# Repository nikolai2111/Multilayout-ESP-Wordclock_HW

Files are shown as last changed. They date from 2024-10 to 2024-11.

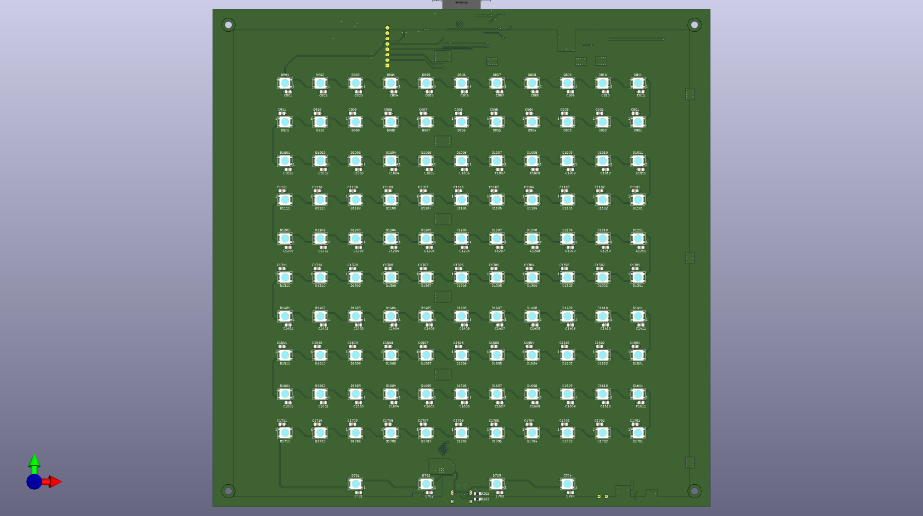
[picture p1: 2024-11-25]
PCB-3D_Top_A.png

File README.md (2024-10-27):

# Multilayout-ESP-Wordclock_HW
This is the first unofficial hardware (PCB) for the [Multilayout-ESP-Wordclock](https://github.com/ESPWortuhr/Multilayout-ESP-Wordclock). The currently supported layout is a 10x11 with the 4 LEDs in the corner (total 114 LEDs). The dimensions are 240 x 240 mm. In the future, maybe more than one PCBs will be available as branch, but we will see how it goes.

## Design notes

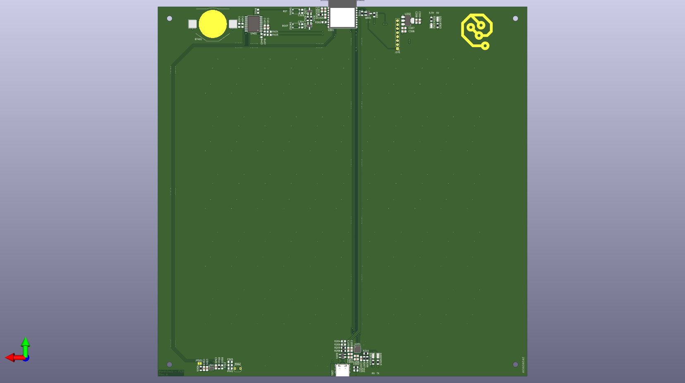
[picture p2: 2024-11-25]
PCB-3D_Bot_A.png

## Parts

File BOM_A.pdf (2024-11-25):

Reference | Value | Footprint | Qty | DNP | Manufacturer | Manufacturer Part no. | Vendor 1 | Vendor 1 Part no. | Vendor 2 | Vendor 2 Part no. | Comment
BT401 | CR2032 | Battery:BatteryHolder_Keystone_3002_1x2032 | 1 | | Keystone Electronics | 2898 | Digikey | 36-2898-ND | LCSC | C6379018
C201, C303, C304, C404, C502 | 0.1µF | Capacitor_SMD:C_0805_2012Metric_Pad1.18x1.45mm_HandSolder | 5 | DNP | Samsung Electro-Mechanics | CL21B104KCFNNNE | Digikey | 1276-6840-1-ND | LCSC | C28233 | Best fit from the JLCPCB "Basic" components
C202, C204, C205, C301, C306, C309, C401, C503 | 10µF | Capacitor_SMD:C_0805_2012Metric_Pad1.18x1.45mm_HandSolder | 8 | | Samsung Electro-Mechanics | CL21A106KOQNNNE | Digikey | 1276-1096-1-ND | LCSC | C1713 | Best fit from the JLCPCB "Basic" components
C203, C305, C505 | 1µF | Capacitor_SMD:C_0805_2012Metric_Pad1.18x1.45mm_HandSolder | 3 | | Samsung Electro-Mechanics | CL21B105KPFNNNE | Digikey | 1276-1275-2-ND | LCSC | C107367 | Best fit from the JLCPCB "Basic" components

C206, C207, C208, C302, C307, C308, C402, C504,
C701, C702, C703, C704, C801, C802, C803, C804, C805, C806, C807, C808, C809, C810, C811, C901, C902, C903, C904, C905, C906, C907, C908, C909, C910, C911, C1001, C1002, C1003, C1004, C1005, C1006, C1007, C1008, C1009, C1010, C1011, C1101, C1102, C1103, C1104, C1105, C1106, C1107, C1108, C1109, C1110, C1111, C1201, C1202, C1203, C1204, C1205, C1206, C1207, C1208, C1209, C1210, C1211, C1301, C1302, C1303, C1304, C1305, C1306, C1307, C1308, C1309, C1310, C1311, C1401, C1402, C1403, C1404, C1405, C1406, C1407, C1408, C1409, C1410, C1411, C1501, C1502, C1503, C1504, C1505, C1506, C1507, C1508, C1509, C1510, C1511, C1601, C1602, C1603, C1604, C1605, C1606, C1607, C1608, C1609, C1610, C1611, C1701, C1702, C1703, C1704, C1705, C1706, C1707, C1708, C1709, C1710, C1711
0.1µF | Capacitor_SMD:C_0805_2012Metric_Pad1.18x1.45mm_HandSolder | 122 | Samsung Electro-Mechanics | CL21B104KCFNNNE | Digikey | 1276-6840-1-ND | LCSC | C28233 | Best fit from the JLCPCB "Basic" components
C403 | 1µF | Capacitor_SMD:C_0805_2012Metric_Pad1.18x1.45mm_HandSolder | 1 | DNP | Samsung Electro-Mechanics | CL21B105KPFNNNE | Digikey | 1276-1275-2-ND | LCSC | C107367 | Best fit from the JLCPCB "Basic" components
C501 | 10µF | Capacitor_SMD:C_0805_2012Metric_Pad1.18x1.45mm_HandSolder | 1 | DNP | Samsung Electro-Mechanics | CL21A106KOQNNNE | Digikey | 1276-1096-1-ND | LCSC | C1713 | Best fit from the JLCPCB "Basic" components
D201 | SP0503BAHTG | Package_TO_SOT_SMD:SOT-143_Handsoldering | 1 | | Littelfuse Inc. | SP0503BAHTG | Digikey | F2715CT-ND | LCSC | C7074
D202, D203 | green | LED_SMD:LED_0805_2012Metric_Pad1.15x1.40mm_HandSolder | 2 | | Lite-On Inc. | LTST-C171GKT | Digikey | 160-1423-1-ND | LCSC | C913075
D301 | red | LED_SMD:LED_0805_2012Metric_Pad1.15x1.40mm_HandSolder | 1 | | Lite-On Inc. | LTST-C171KRKT | Digikey | 160-1427-1-ND | LCSC | C284871
D302 | orange | LED_SMD:LED_0805_2012Metric_Pad1.15x1.40mm_HandSolder | 1 | | Lite-On Inc. | LTST-C170KFKT | Digikey | 160-1413-1-ND | LCSC | C284931
D701, D702, D703, D704, D801, D802, D803, D804, D805, D806, D807, D808, D809, D810, D811, D901, D902, D903, D904, D905, D906, D907, D908, D909, D910, D911, D1001, D1002, D1003, D1004, D1005, D1006, D1007, D1008, D1009, D1010, D1011, D1101, D1102, D1103, D1104, D1105, D1106, D1107, D1108, D1109, D1110, D1111, D1201, D1202, D1203, D1204, D1205, D1206, D1207, D1208, D1209, D1210, D1211, D1301, D1302, D1303, D1304, D1305, D1306, D1307, D1308, D1309, D1310, D1311, D1401, D1402, D1403, D1404, D1405, D1406, D1407, D1408, D1409, D1410, D1411, D1501, D1502, D1503, D1504, D1505, D1506, D1507, D1508, D1509, D1510, D1511, D1601, D1602, D1603, D1604, D1605, D1606, D1607, D1608, D1609, D1610, D1611, D1701, D1702, D1703, D1704, D1705, D1706, D1707, D1708, D1709, D1710, D1711
WS2812B | LED_SMD:LED_WS2812B_PLCC4_5.0x5.0mm_P3.2mm | 114 | - | WS2812B | Digikey | 1568-COM-16347CT-ND | LCSC | C22461793
J101 | Conn_01x08_Pin | Connector_PinHeader_2.54mm:PinHeader_1x08_P2.54mm_Vertical | 1 | DNP | - | - | - | - | - | -
J201 | USB_C_Receptacle_US B2.0_16P | Connector_USB:USB_C_Receptacle_GCT_USB4105-xx-A_16P_TopMnt_Horizontal | 1 | | GCT | USB4105-GF-A | Digikey | 2073-USB4105-GF-ACT-ND | LCSC | C3020560
Q201, Q202 | NPN BJT | Package_TO_SOT_SMD:SOT-23_Handsoldering | 2 | | - | - | Digikey | 353-MMS8050-H-TPCT-ND | LCSC | C49581 | General purpose NPN transistor
Q601 | BSS138 | Package_TO_SOT_SMD:SOT-23_Handsoldering | 1 | | - | BSS138 | Digikey | BSS138CT-ND | LCSC | C518792 | General purpose N-channel MOSFET
R201, R208, R209 | 0R | Resistor_SMD:R_0805_2012Metric_Pad1.20x1.40mm_HandSolder | 3 | | YAGEO | RC0805JR-070RL | Digikey | 311-0.0ARCT-ND | LCSC | C96345 | Best fit from the JLCPCB "Basic" components
R202, R203, R303 | 5.1k | Resistor_SMD:R_0805_2012Metric_Pad1.20x1.40mm_HandSolder | 3 | | YAGEO | RC0805FR-075K1L | Digikey | 311-5.10KCRCT-ND | LCSC | C84375 | Best fit from the JLCPCB "Basic" components
R204, R205, R401, R404, R405, R503 | 0R | Resistor_SMD:R_0805_2012Metric_Pad1.20x1.40mm_HandSolder | 6 | DNP | YAGEO | RC0805JR-070RL | Digikey | 311-0.0ARCT-ND | LCSC | C96345 | Best fit from the JLCPCB "Basic" components
R206 | 22.1k | Resistor_SMD:R_0805_2012Metric_Pad1.20x1.40mm_HandSolder | 1 | | YAGEO | RC0805FR-0722K1L | Digikey | 311-22.1KCRCT-ND | LCSC | C273840
R207 | 47.5k | Resistor_SMD:R_0805_2012Metric_Pad1.20x1.40mm_HandSolder | 1 | | YAGEO | RC0805FR-0747K5L | Digikey | 311-47.5KCRCT-ND | LCSC | C137519
R210, R213, R214, R304, R504 | 1k | Resistor_SMD:R_0805_2012Metric_Pad1.20x1.40mm_HandSolder | 5 | | YAGEO | RC0805FR-071KL | Digikey | 311-1.00KCRCT-ND | LCSC | C95781 | Best fit from the JLCPCB "Basic" components
R211, R212, R301, R505, R601, R602 | 10k | Resistor_SMD:R_0805_2012Metric_Pad1.20x1.40mm_HandSolder | 6 | | YAGEO | RC0805FR-0710KL | Digikey | 311-10.0KCRCT-ND | LCSC | C84376 | Best fit from the JLCPCB "Basic" components
R302, R402, R403, R501 | 10k | Resistor_SMD:R_0805_2012Metric_Pad1.20x1.40mm_HandSolder | 4 | DNP | YAGEO | RC0805FR-0710KL | Digikey | 311-10.0KCRCT-ND | LCSC | C84376 | Best fit from the JLCPCB "Basic" components
R502 | LDR07 | OptoDevice:R_LDR_5.1x4.3mm_P3.4mm_Vertical | 1 | DNP | - | - | - | - | - | -
SW301, SW302 | SW_Push | Button_Switch_SMD:SW_SPST_PTS810 | 2 | | C&K; | PTS810 SJK 250 SMTR LFS | Digikey | CKN10503CT-ND | LCSC | C221896
U201 | CP2102N-Axx-xQFN24 | Package_DFN_QFN:QFN-24-1EP_4x4mm_P0.5mm_EP2.6x2.6mm_ThermalVias | 1 | | Silicon Labs | CP2102N-A02-GQFN24R | Digikey | 336-5888-2-ND | LCSC | C969151
U301 | ESP32-C3-WROOM-02 | RF_Module:ESP32-C3-WROOM-02 | 1 | | Espressif Systems | ESP32-C3-WROOM-02-N4 | Digikey | 1965-ESP32-C3-WROOM-02 -N4TR-ND | LCSC | C2934560
U302 | TLV1117LV33 | Package_TO_SOT_SMD:SOT-223-3_TabPin2 | 1 | | Texas Instruments | TLV1117LV33DCYR | Digikey | 296-28778-2-ND | LCSC | C15578
U401 | DS3231M | Package_SO:SOIC-16W_7.5x10.3mm_P1.27mm | 1 | | Analog Devices Inc./Maxim Integrated | DS3231M+TRL | Digikey | DS3231M+TRLCT-ND | LCSC | C9866 | LCSC, only has the compatible DS3231SN in stock
U501 | BH1750xxx-xx | Package_TO_SOT_SMD:HVSOF6 | 1 | | Rohm Semiconductor | BH1750FVI-TR | Digikey | BH1750FVICT-ND | LCSC | C78960

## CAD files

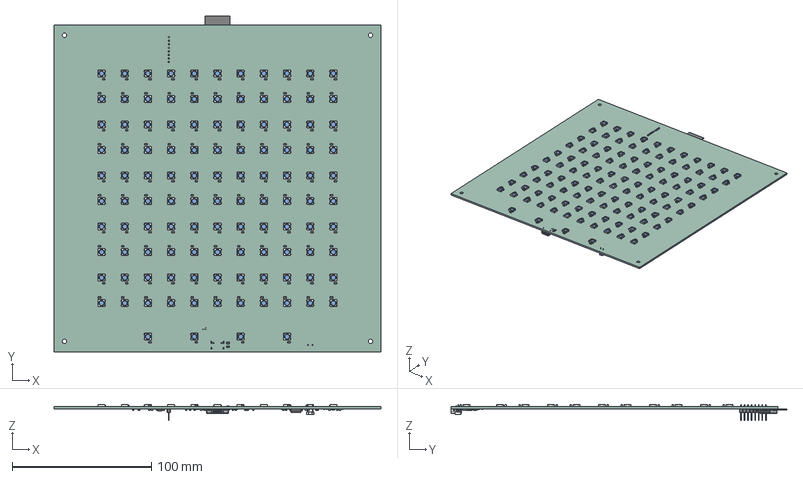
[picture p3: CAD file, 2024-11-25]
ESP-Wordclock_A.step
235.0 x 241.2 x 11.8 mm
C_0805_2012Metric x 140
LED_WS2812B_PLCC4_50x50mm_P32mm x 114
R_0805_2012Metric x 29
SOT_23 x 3
SOT_223
USB_C_Receptacle_16P_TopMnt_Horizontal_GCT_USB4105-xx-A
R_LDR_5.1x4.3mm_P3.4mm_Vertical
LED_0805_2012Metric x 4
SOIC_16W_75x103mm_P127mm
ESP32-C3-WROOM-02
QFN-24-1EP_4x4mm_Pitch0.5mm
PinHeader_1x08_P254mm_Vertical
SOT_143
HVSOF6
ESP-Wordclock_PCB

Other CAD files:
ESP-Wordclock.step

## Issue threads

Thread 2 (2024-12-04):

Remove UART LEDs

nikolai2111, 2024-12-04:
Remove the ledss D202 & D203 and its resistors R213 & R214, because the gpios are not configured by default, so the leds are not working.

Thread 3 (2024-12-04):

No external pull-up resistors

nikolai2111, 2024-12-04:
I2C needs pull-up resistors. The board does not have external pull-up resistors so the internal of the ESP32-C3 has to be used in code!

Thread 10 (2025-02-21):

USB-C PD driver

dbambus, 2025-02-21:
Hey,

Would a USB-C PD be possible? With a 12V input, there might be better power handling capabilities.

Mit freundlichen Grüßen
David

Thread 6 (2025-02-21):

Mounting holes

dbambus, 2025-02-21:
Hey,

an addition would be to place mounting holes for wall mounting the clock.

Suggestion would be:

- Top Mid
- 5cm Left and 5cm right from the mid

Mit freundlichen Grüßen
David

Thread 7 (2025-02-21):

Solder bridges for Vcc LEDs

dbambus, 2025-02-21:
Hey,

some prefer not to have status LEDs for VCC on the PCB. Maybe some solder Bridges to cu would be good.

Mit freundlichen Grüßen
David

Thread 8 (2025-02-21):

Pinout after the last LED

dbambus, 2025-02-21:
Hey,

there are frame designs which use additional stripes around the outer perimeter of the clock to enable some sort of Ambient light. A pinout to glue normal stripes to the back of the clock with traces in the corners.

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

Mit freundlichen Grüßen
David

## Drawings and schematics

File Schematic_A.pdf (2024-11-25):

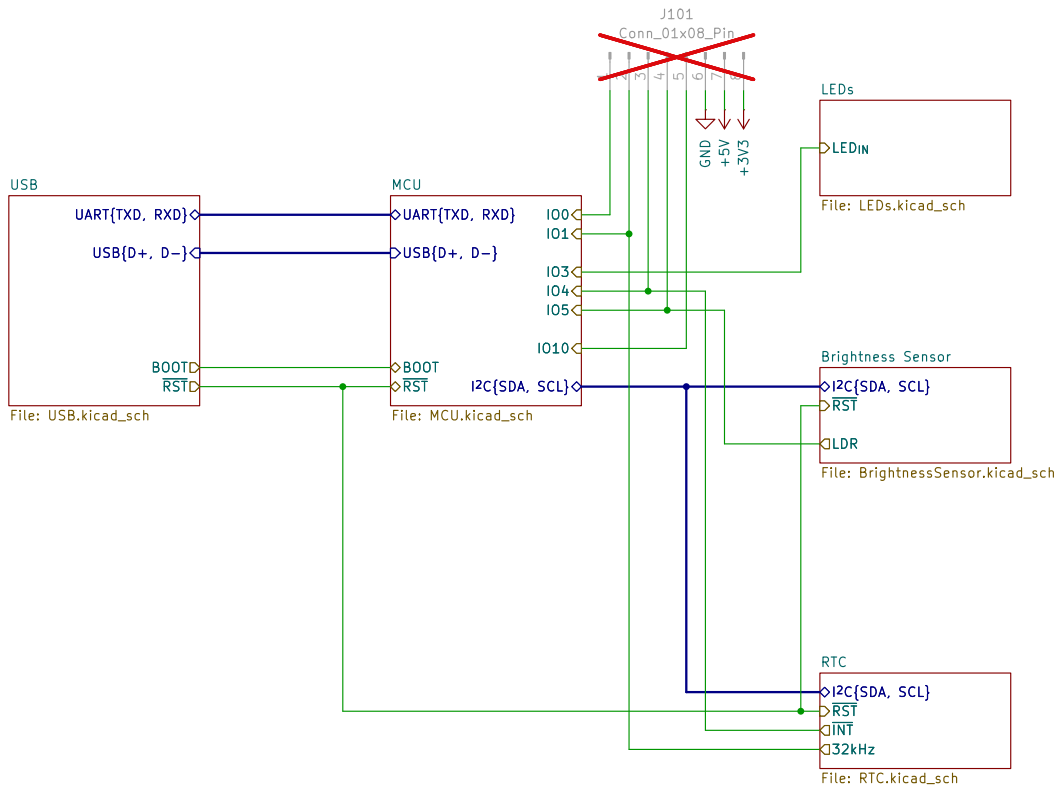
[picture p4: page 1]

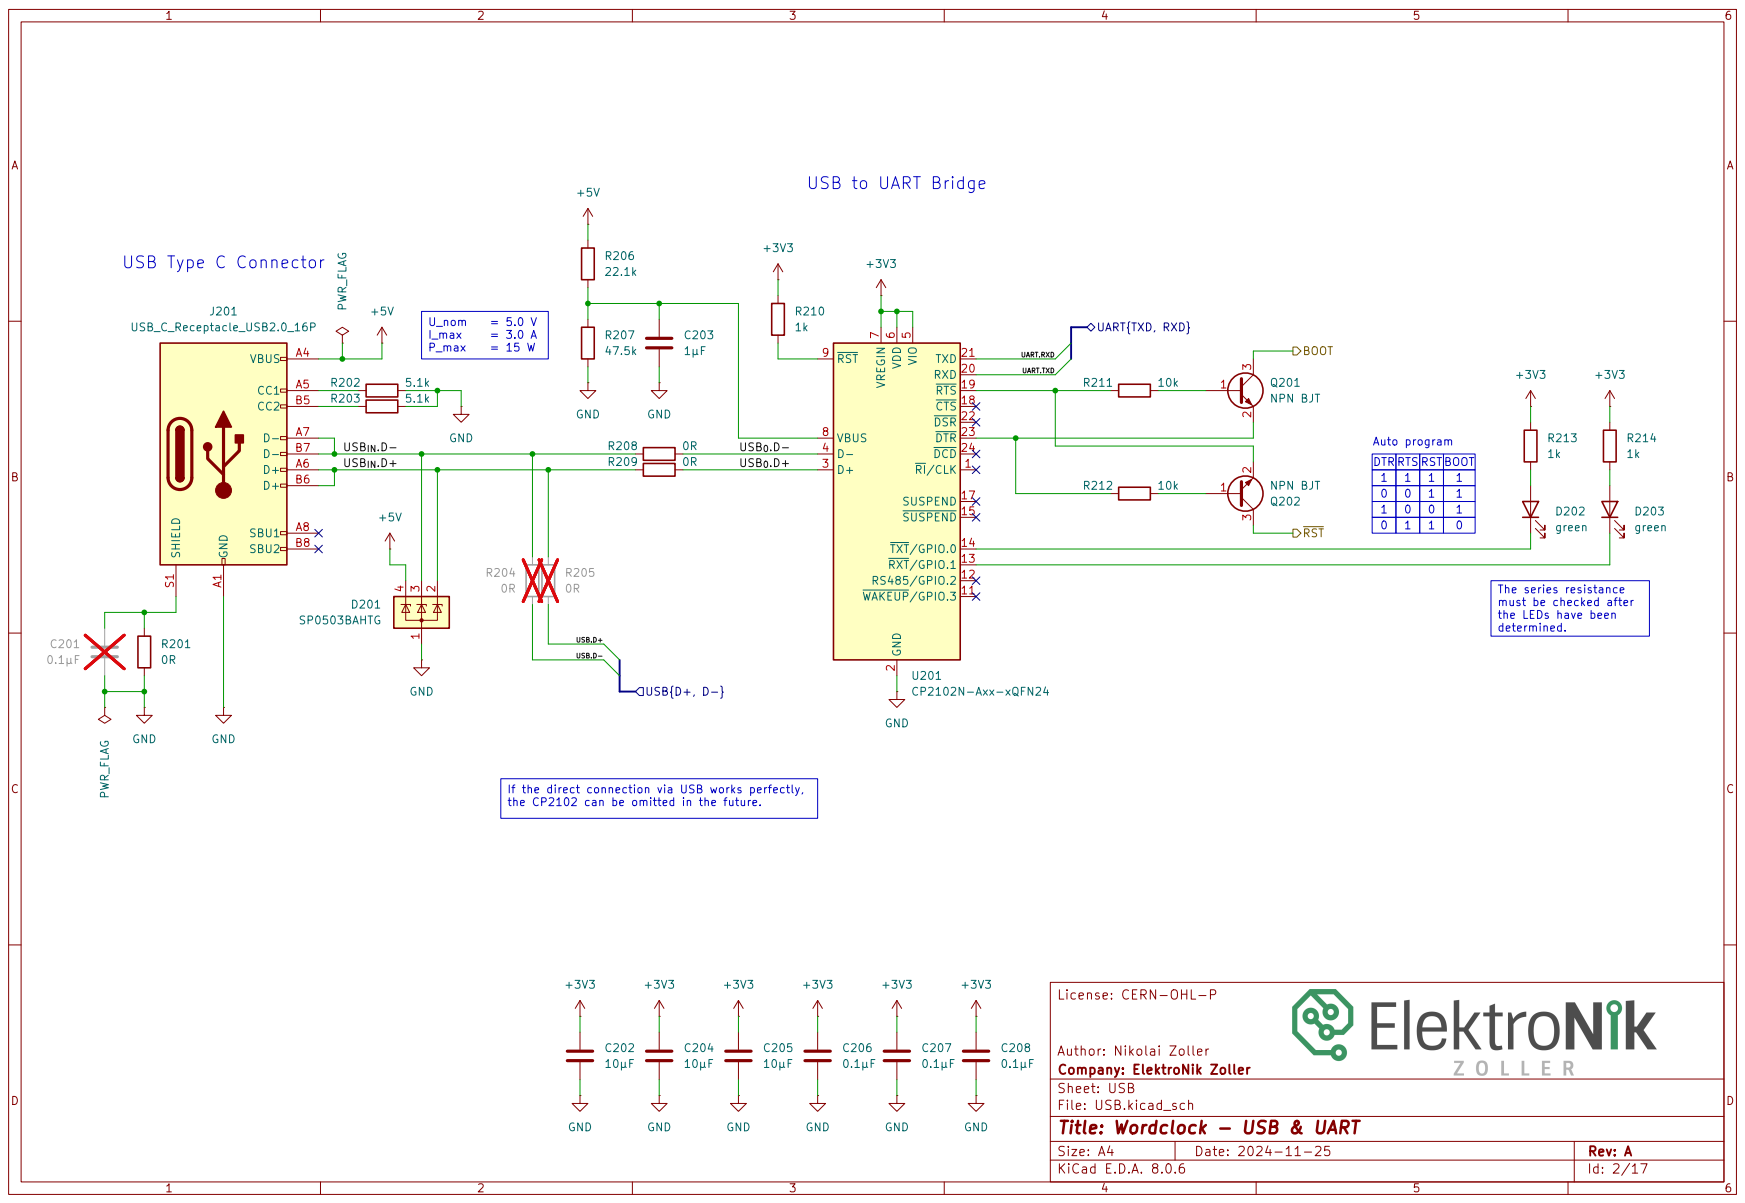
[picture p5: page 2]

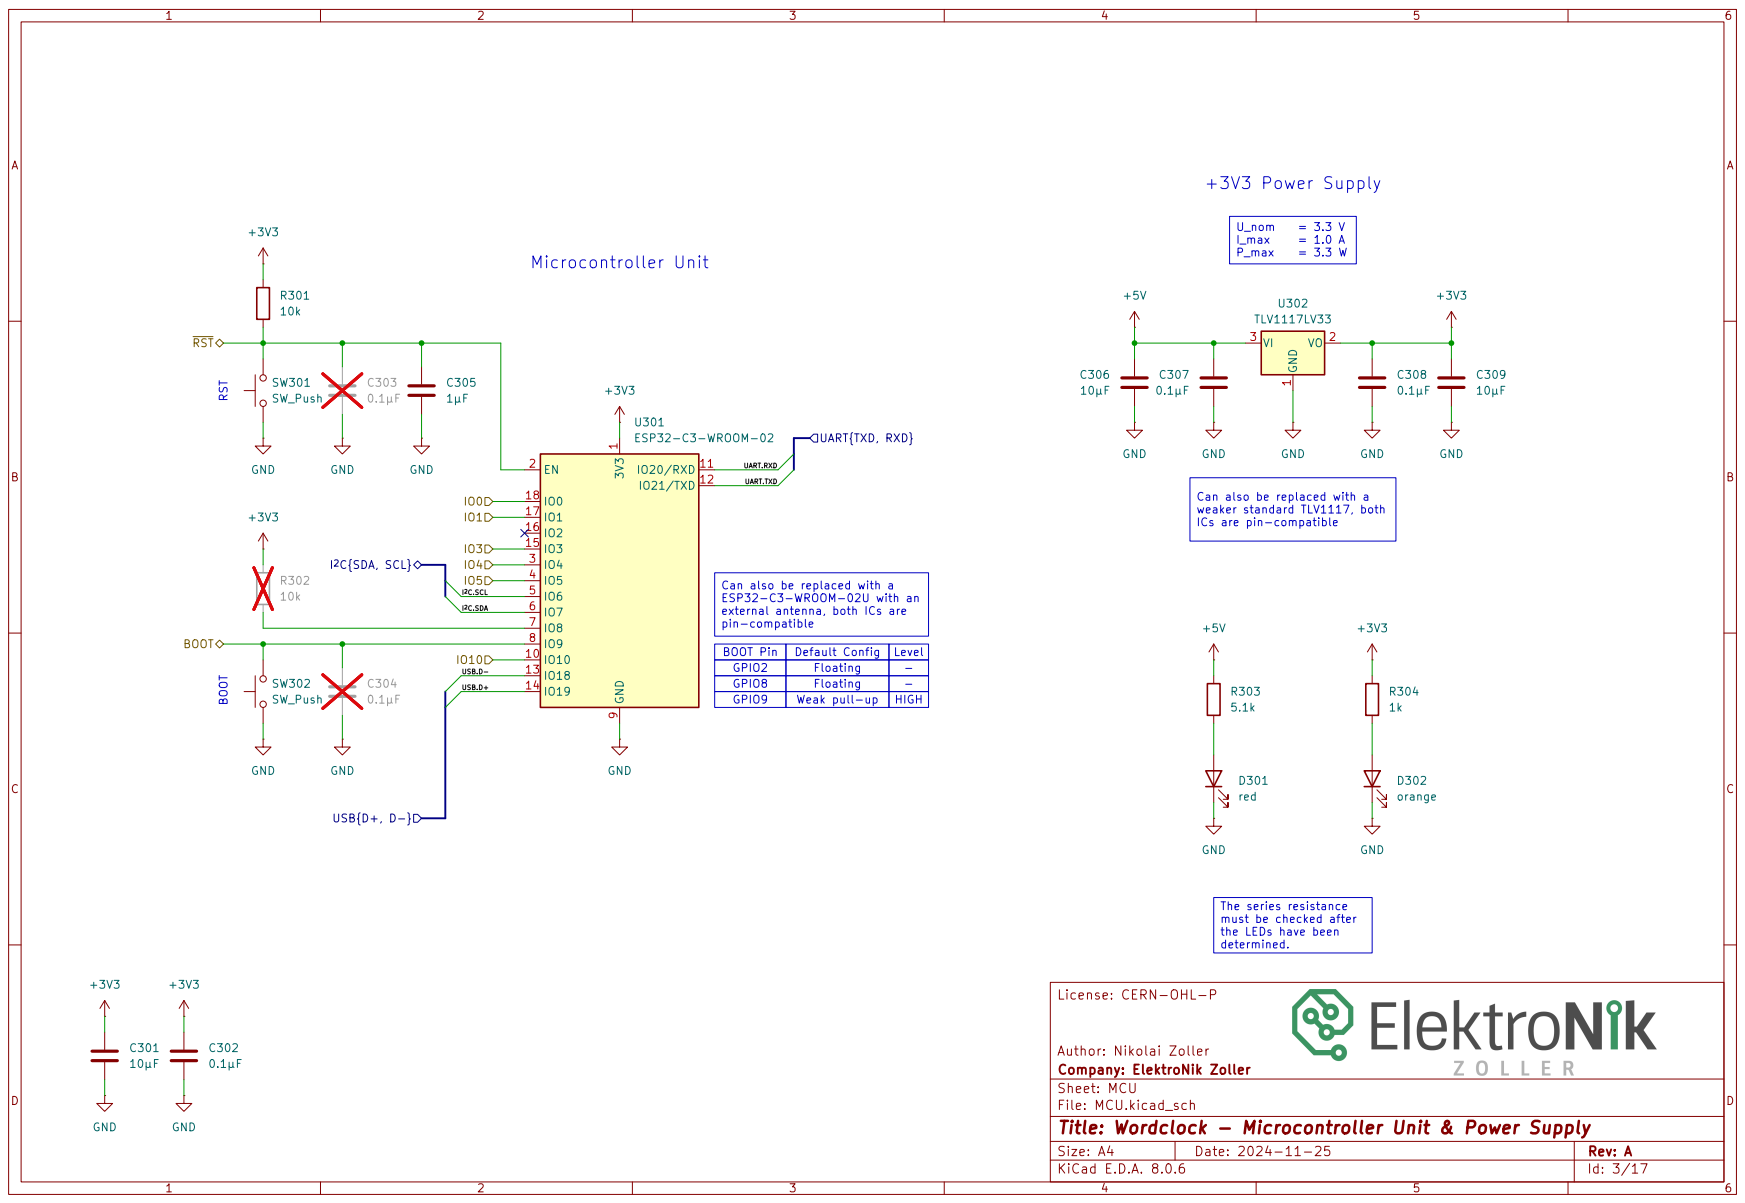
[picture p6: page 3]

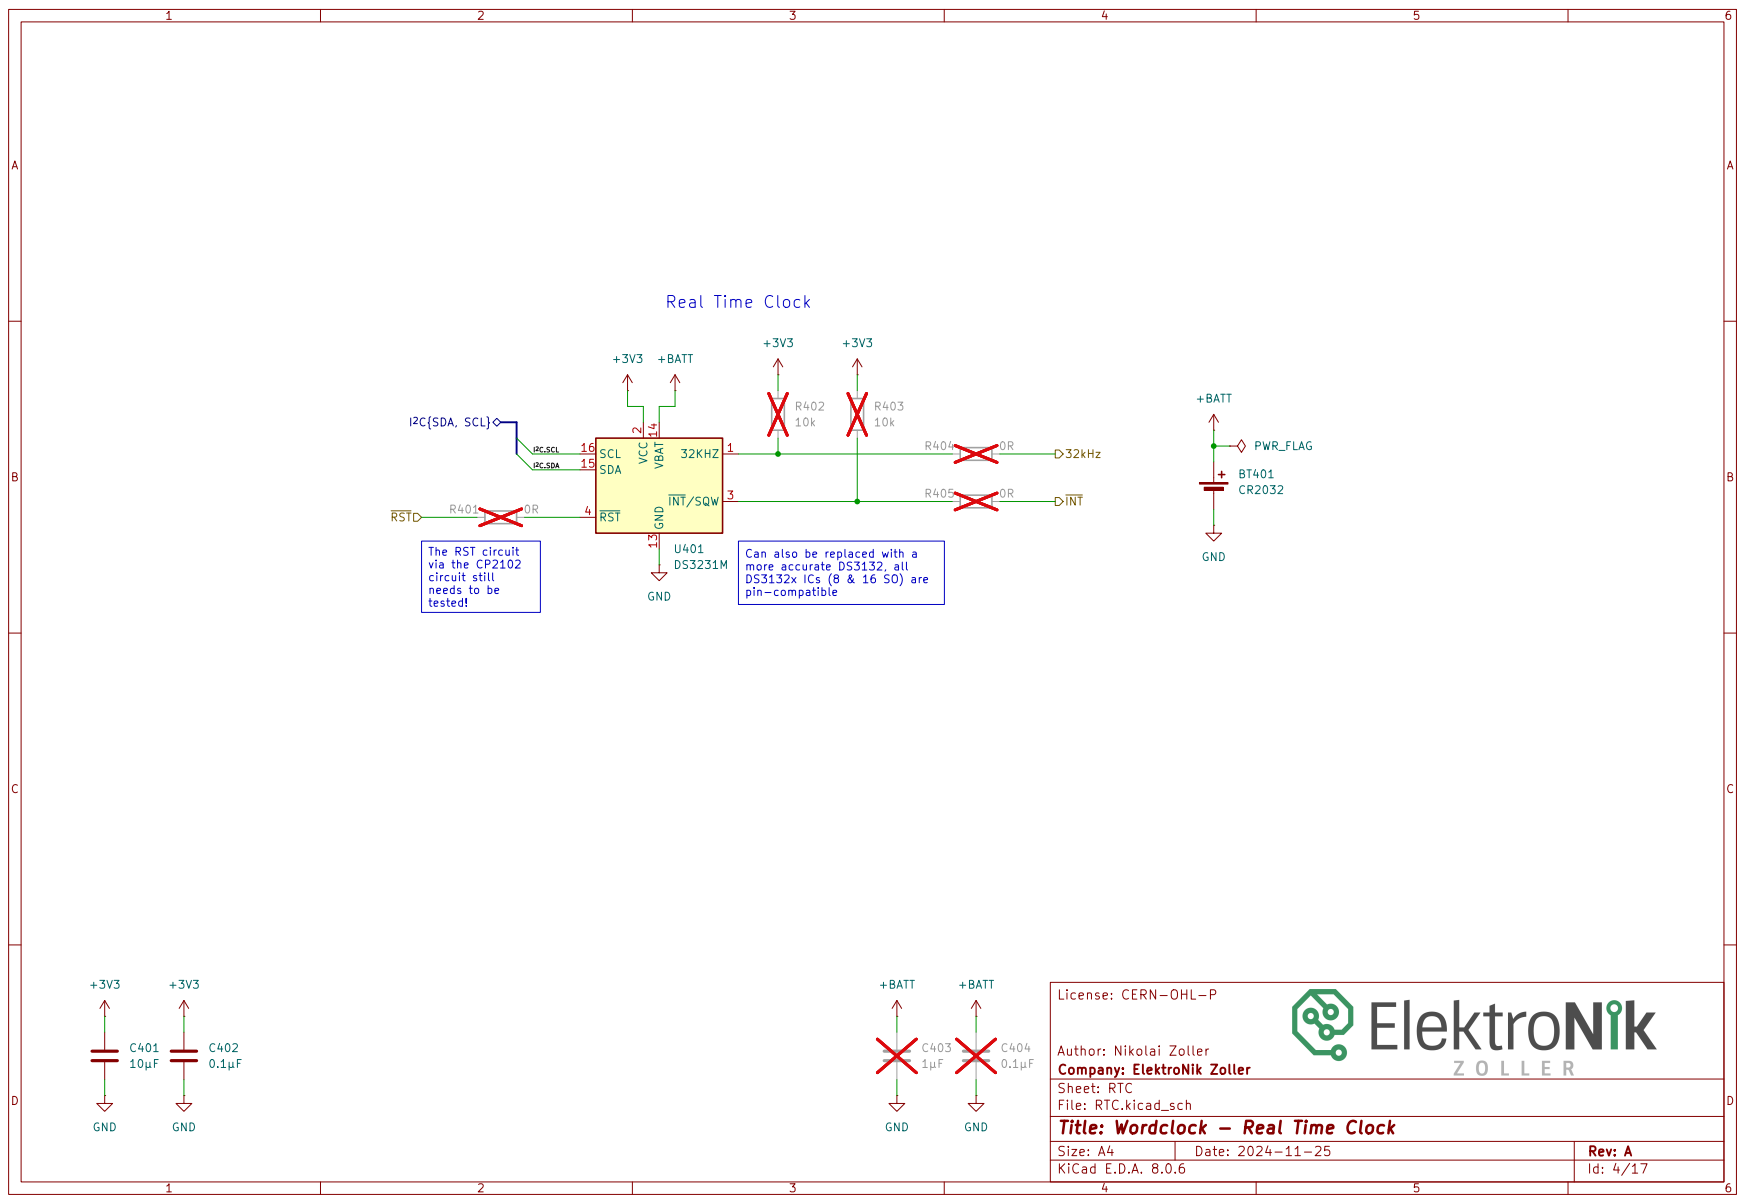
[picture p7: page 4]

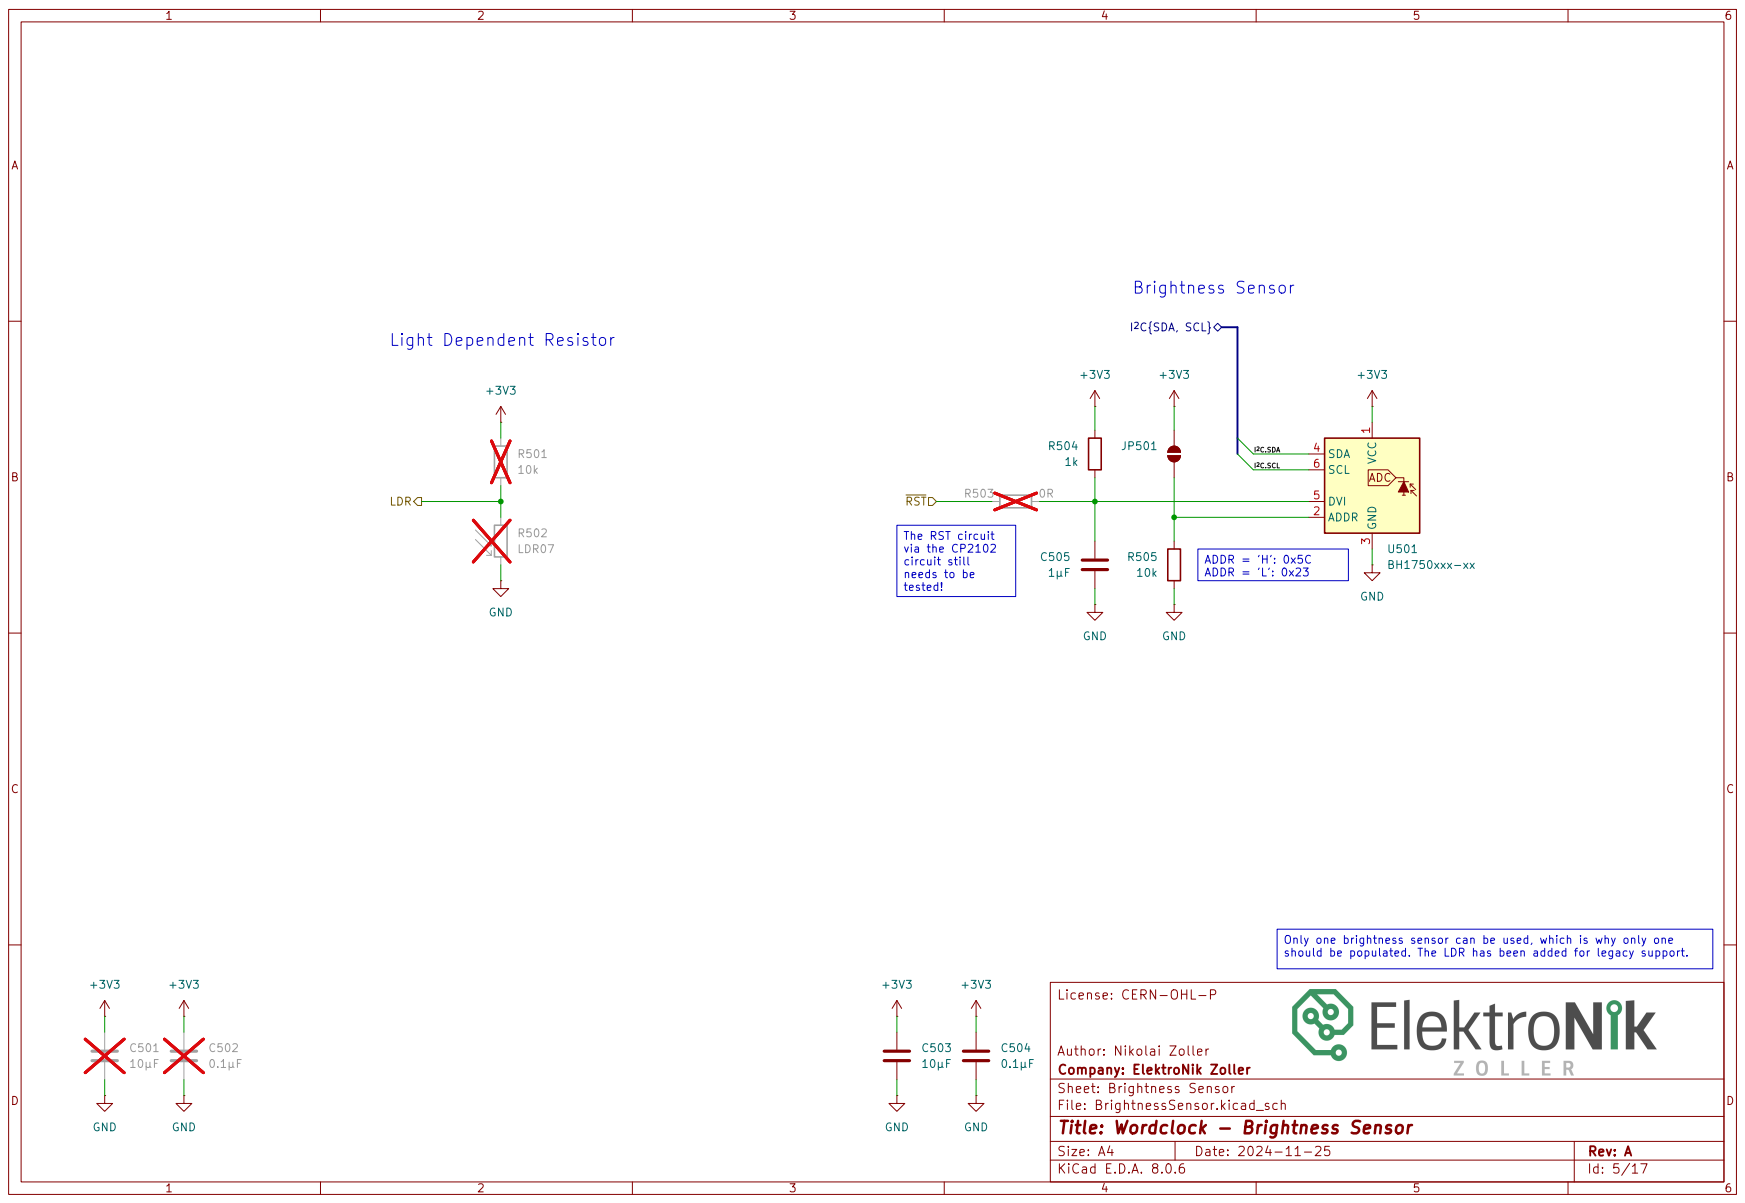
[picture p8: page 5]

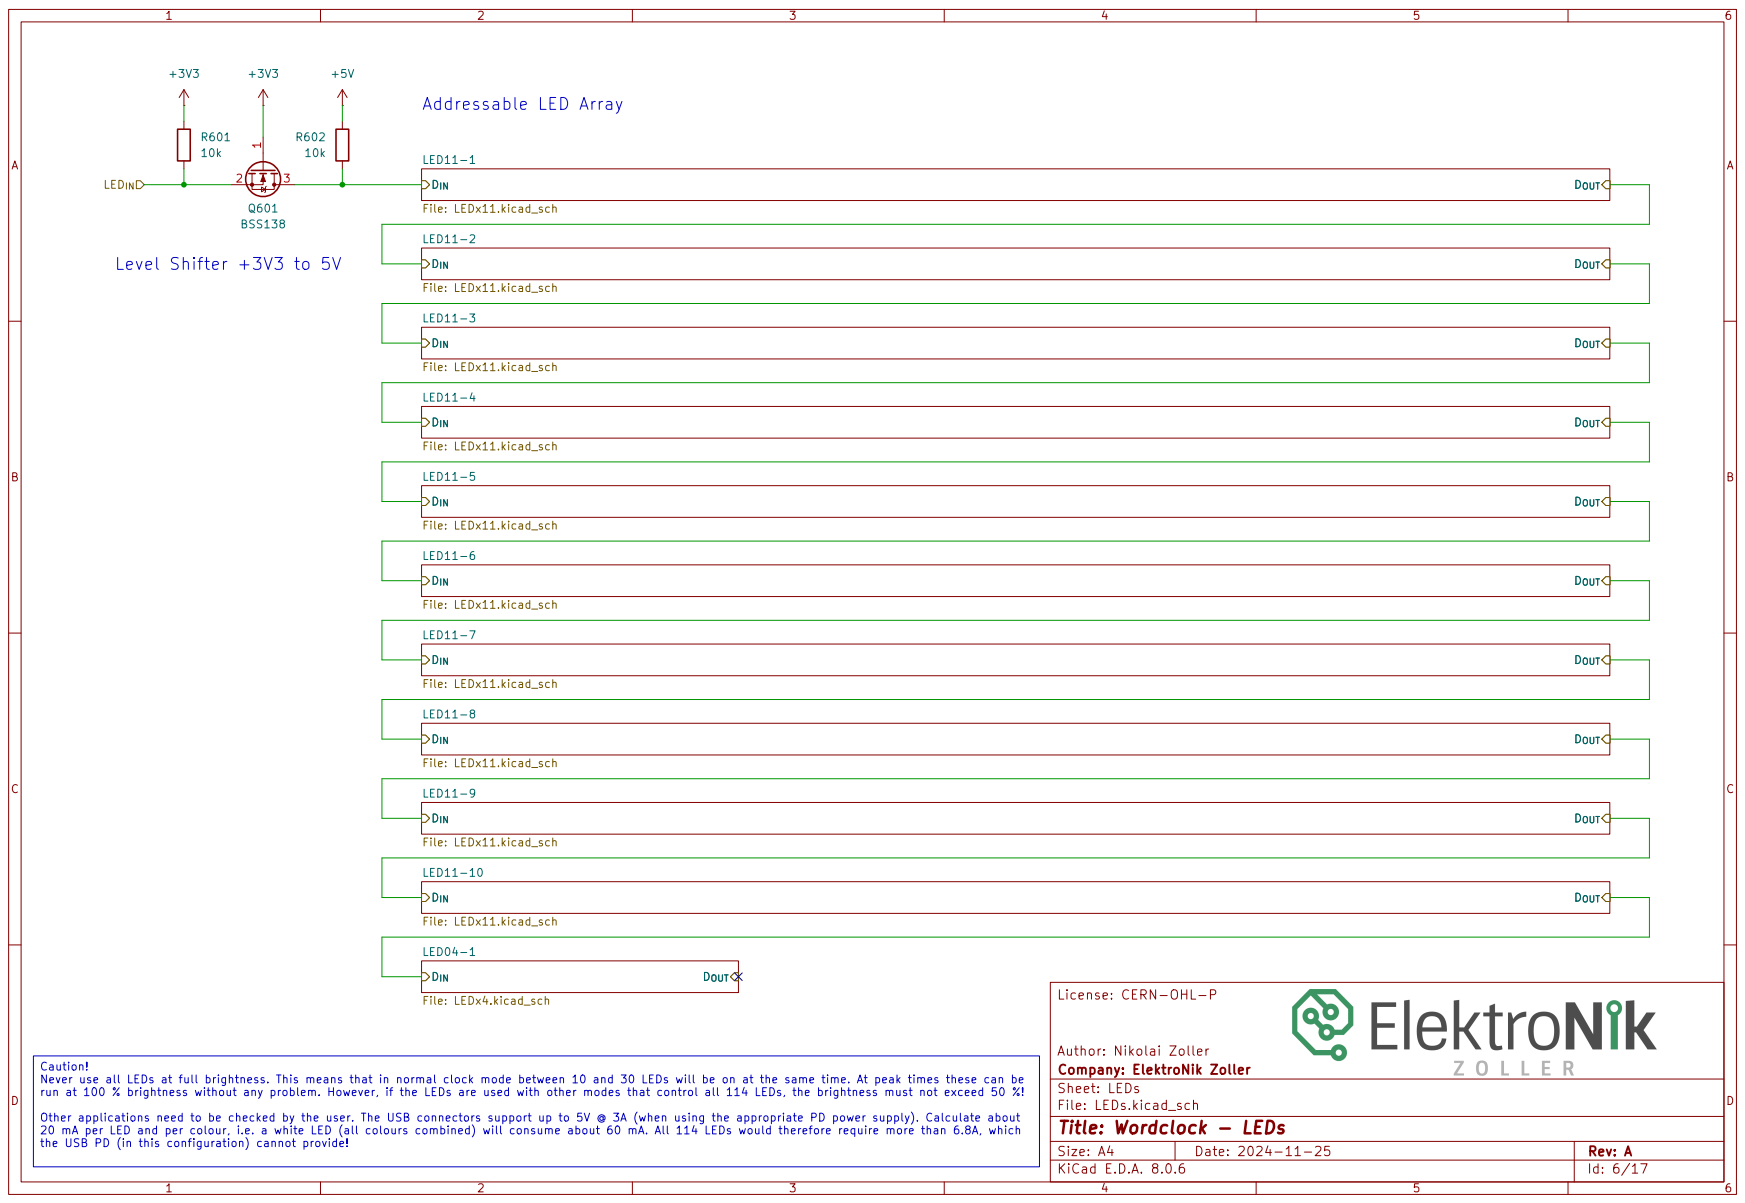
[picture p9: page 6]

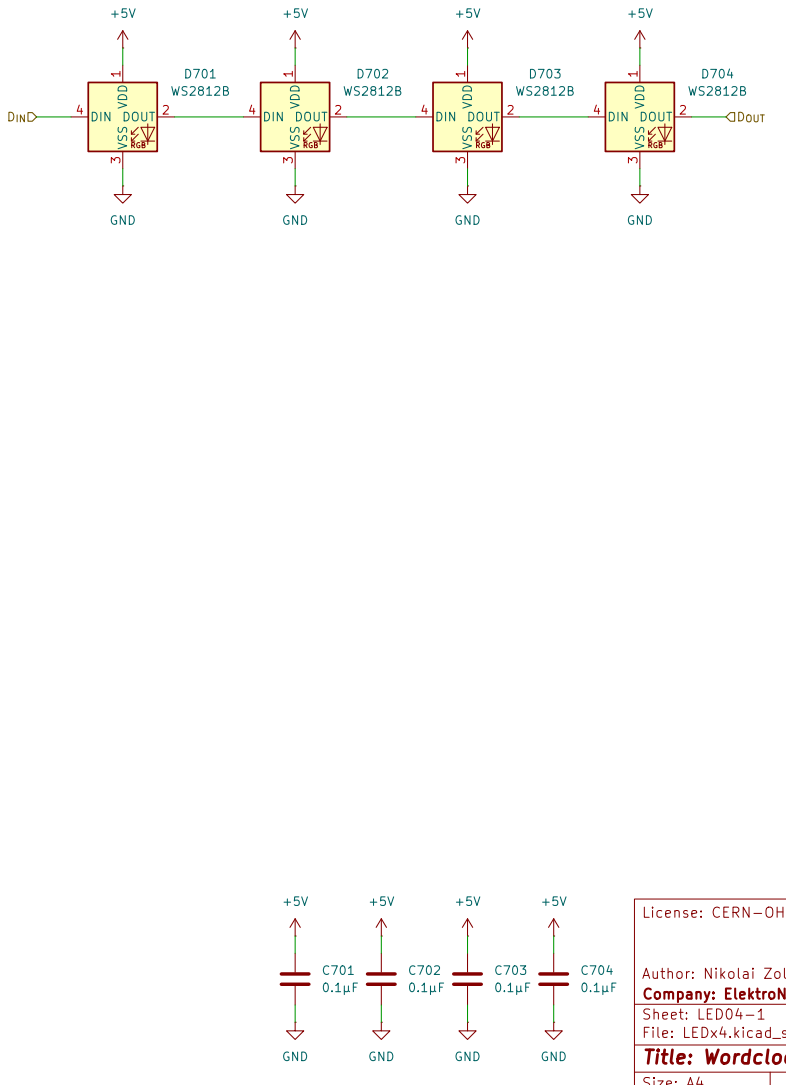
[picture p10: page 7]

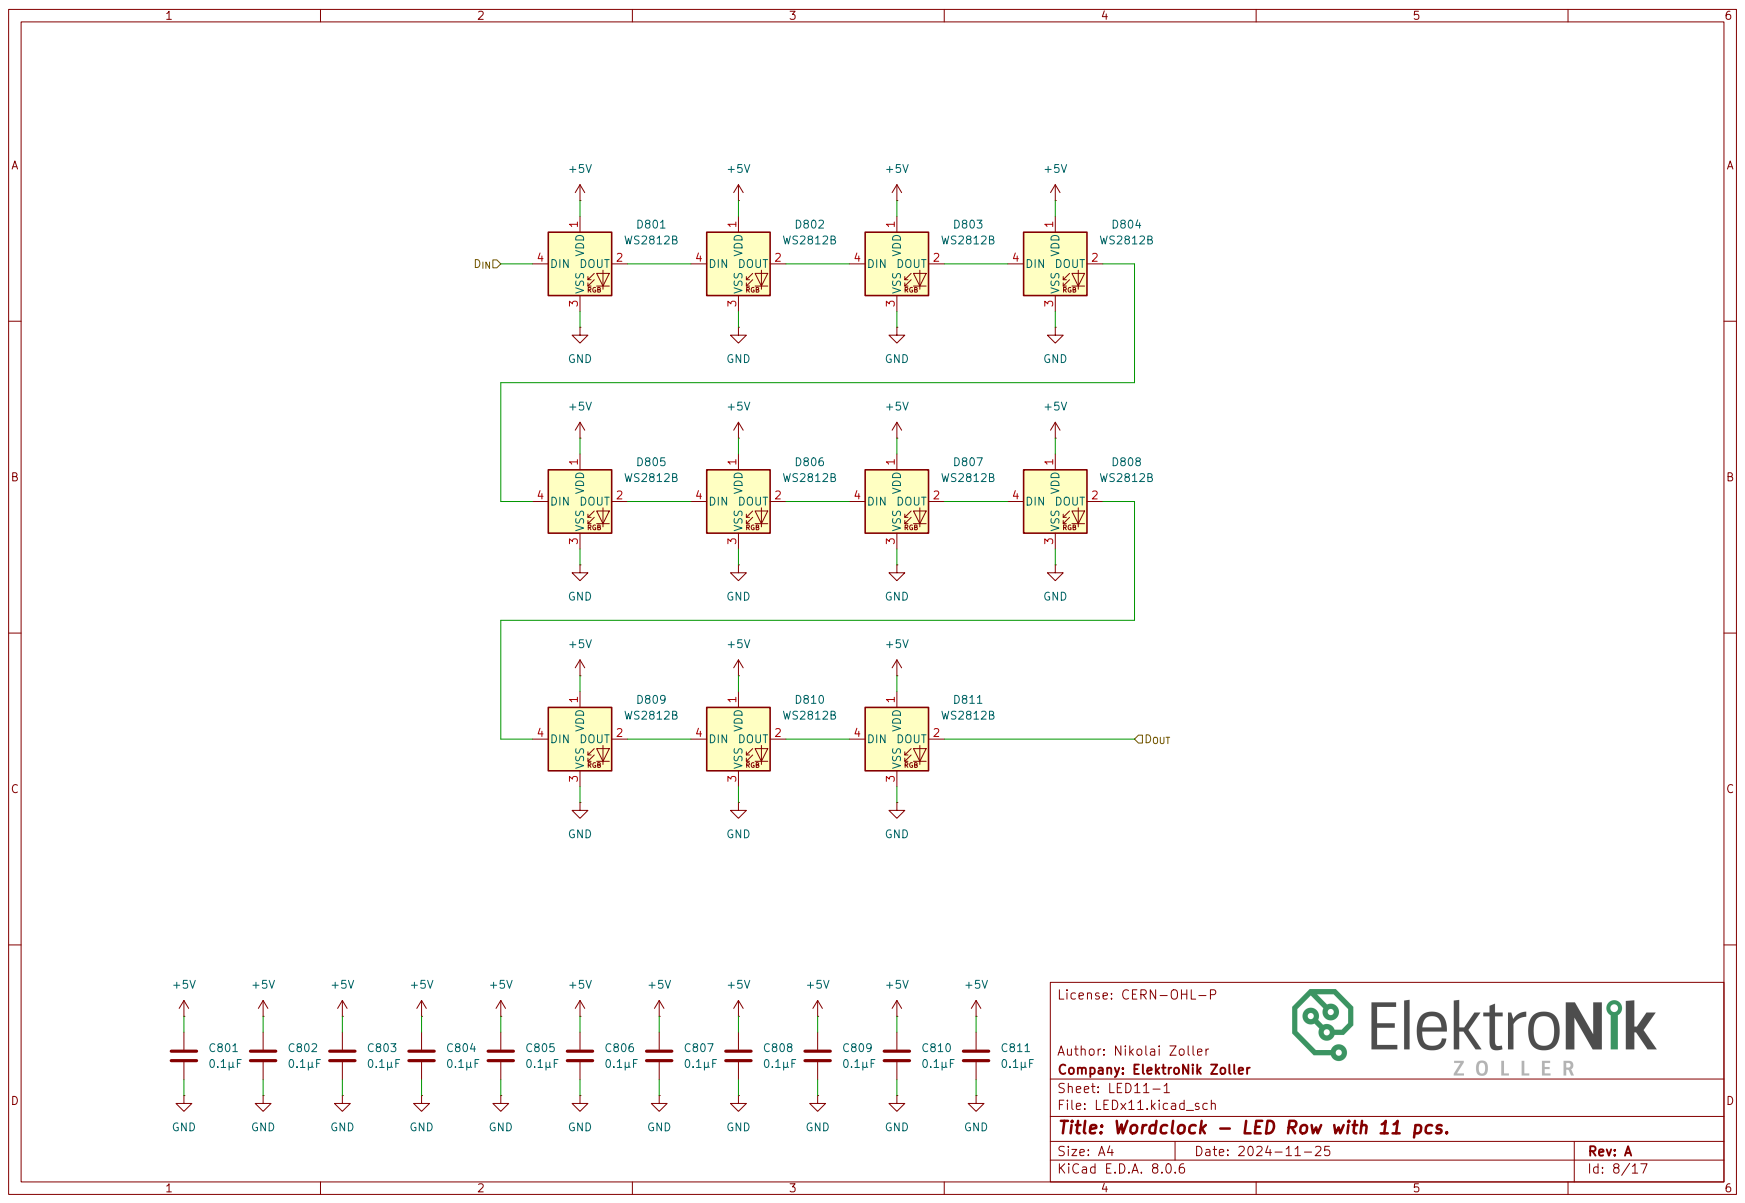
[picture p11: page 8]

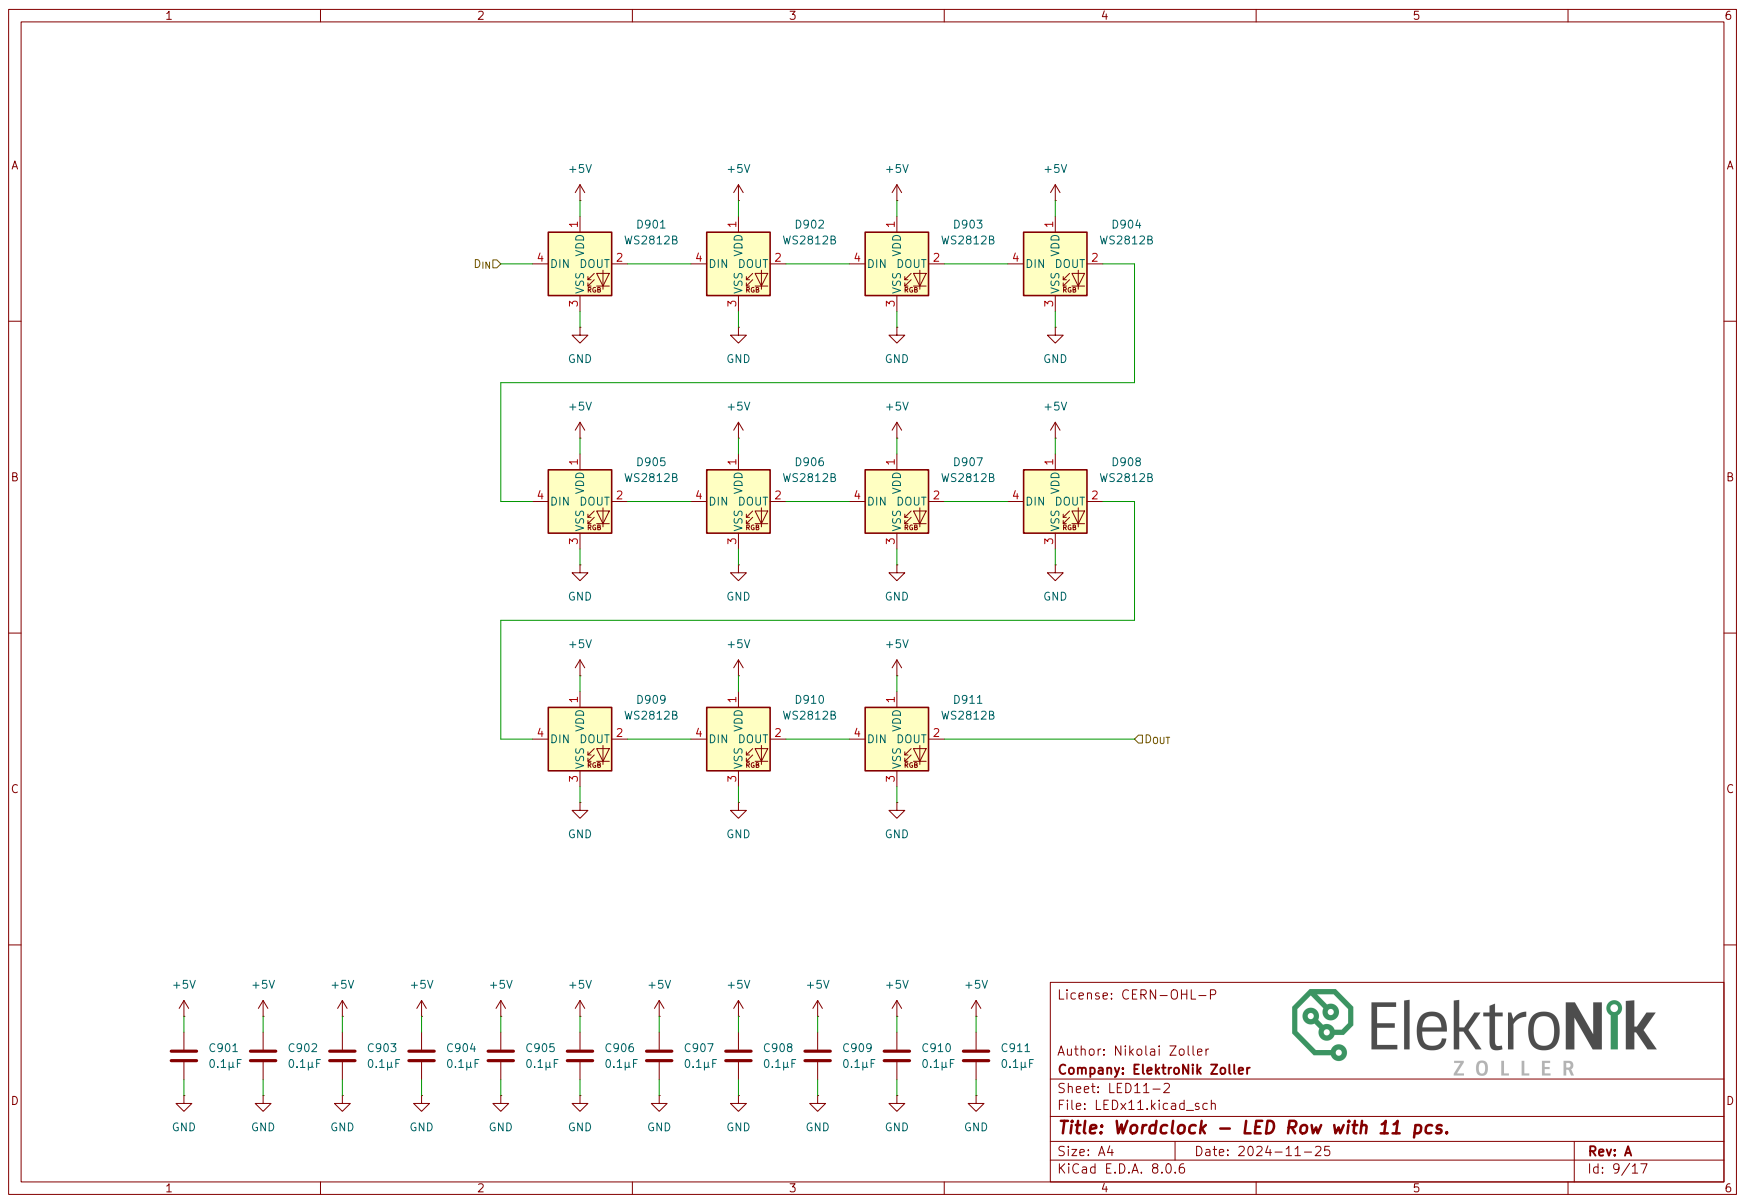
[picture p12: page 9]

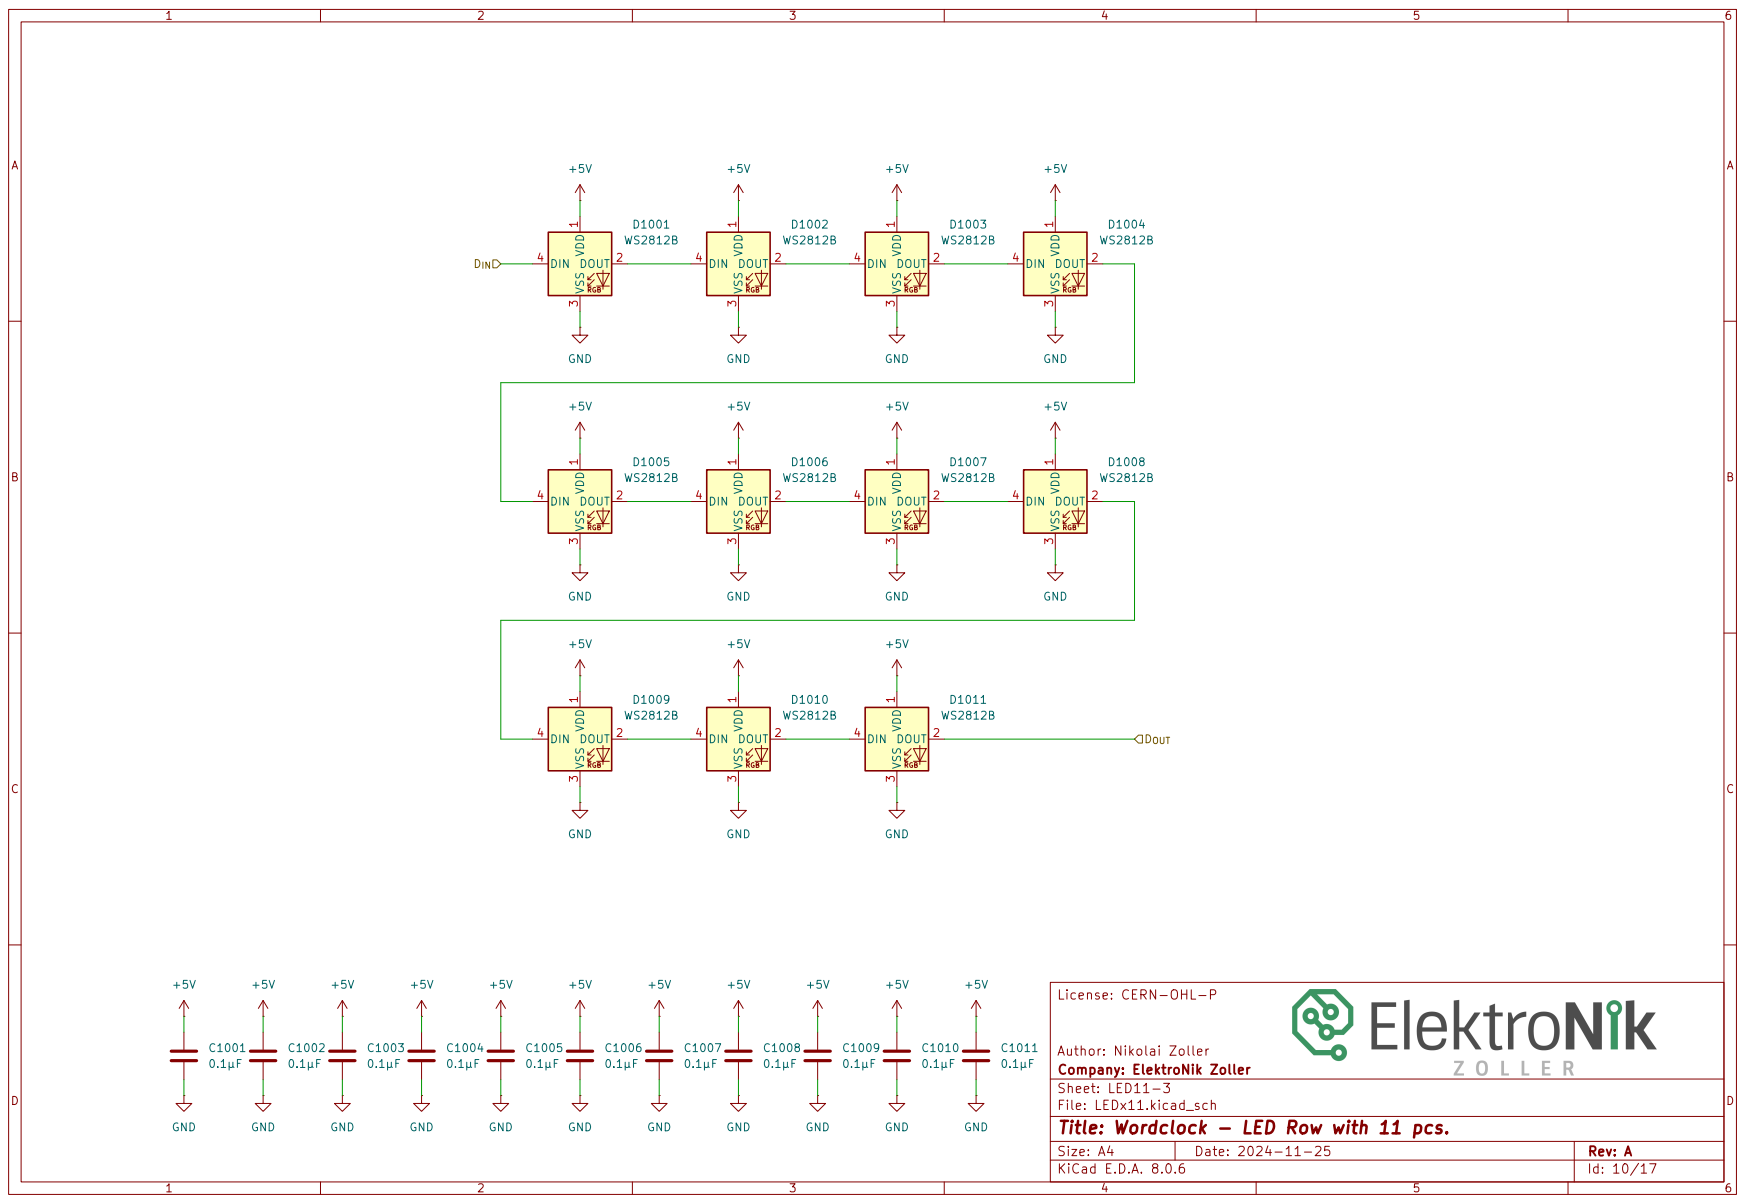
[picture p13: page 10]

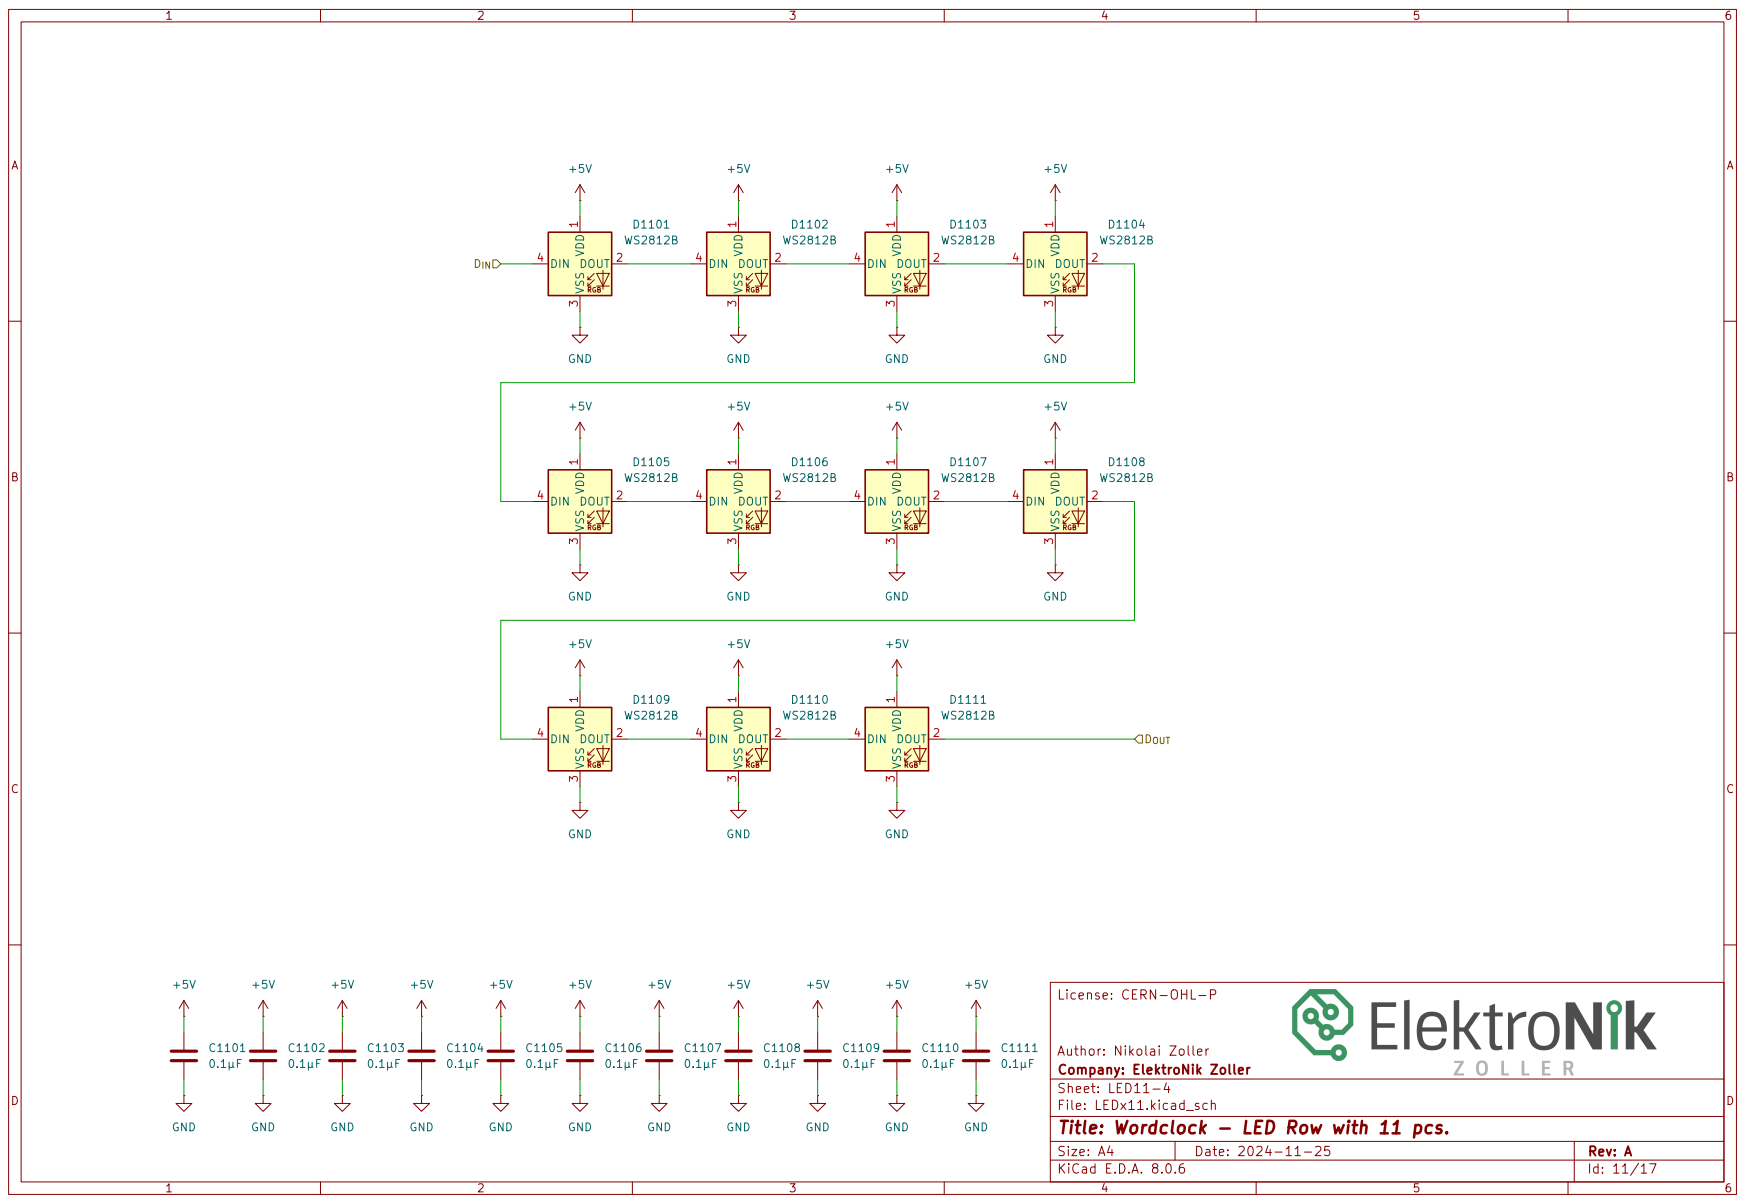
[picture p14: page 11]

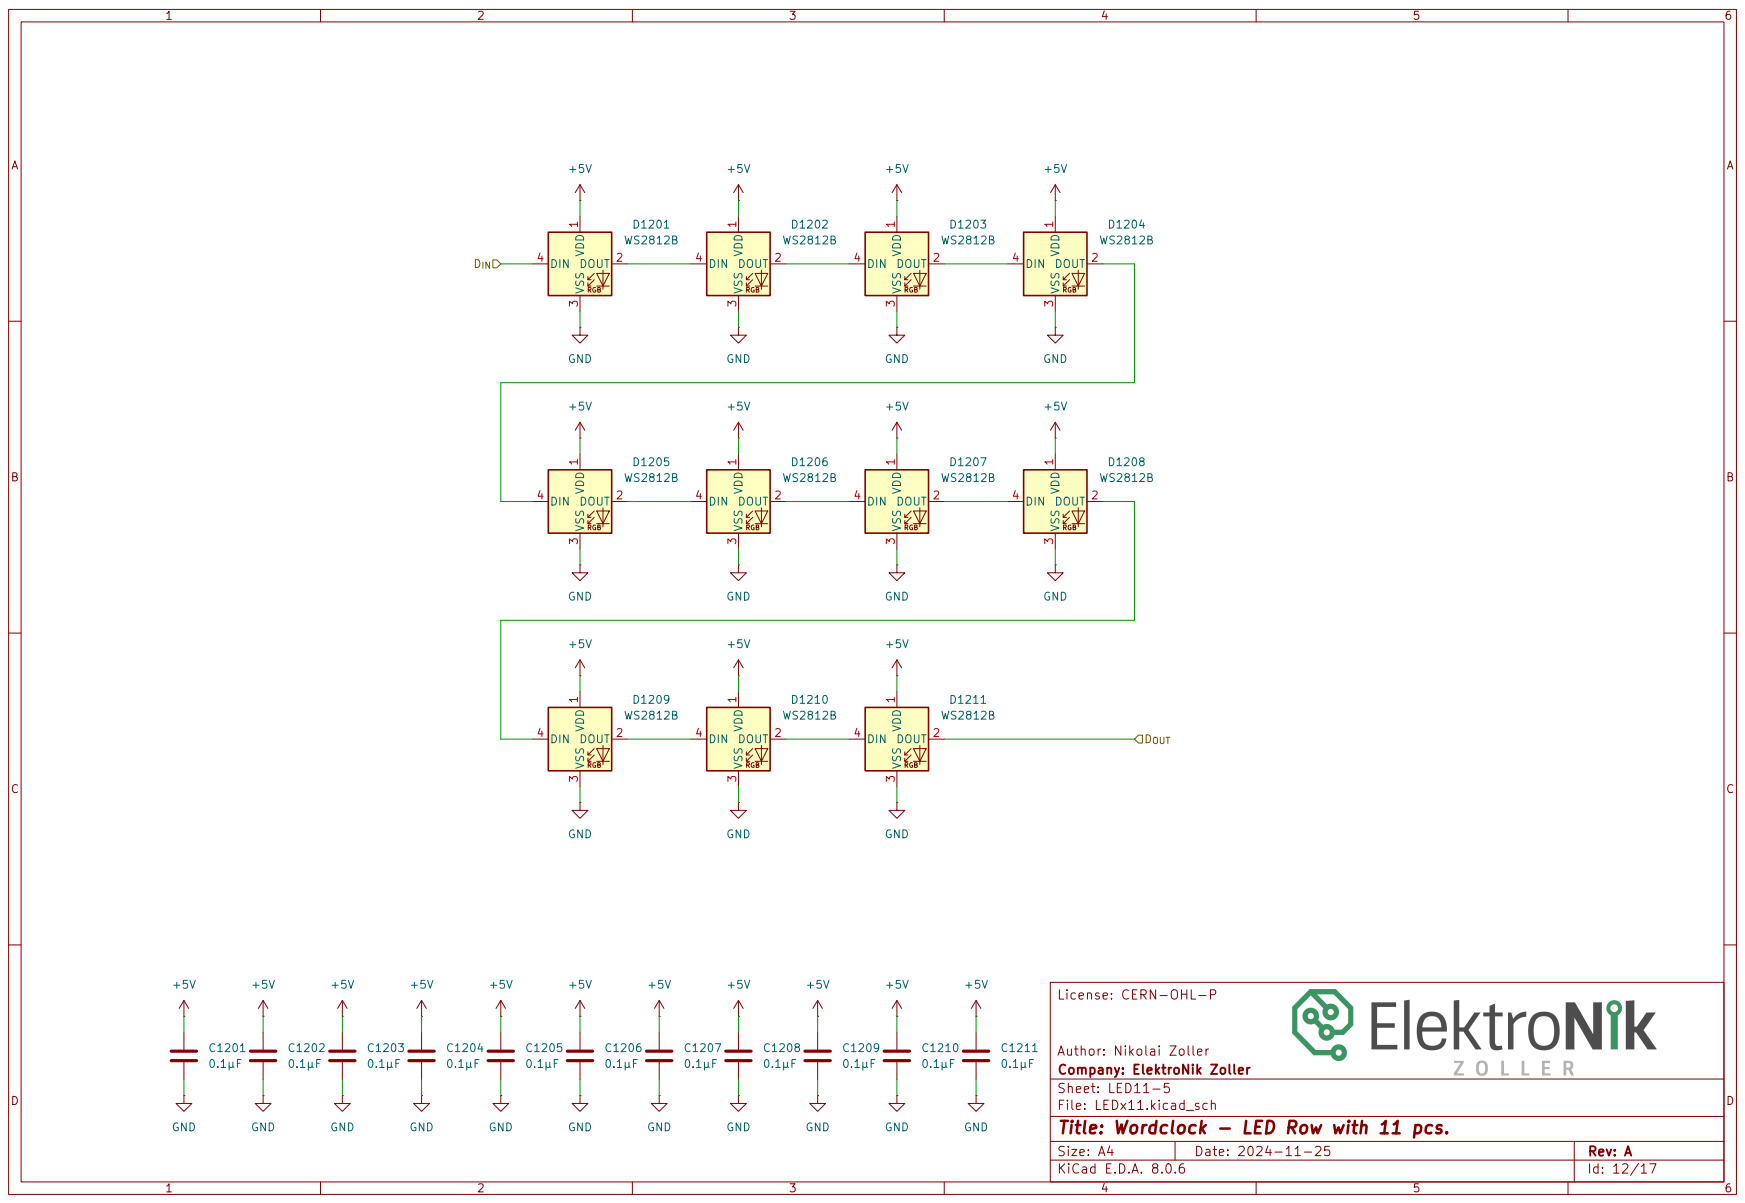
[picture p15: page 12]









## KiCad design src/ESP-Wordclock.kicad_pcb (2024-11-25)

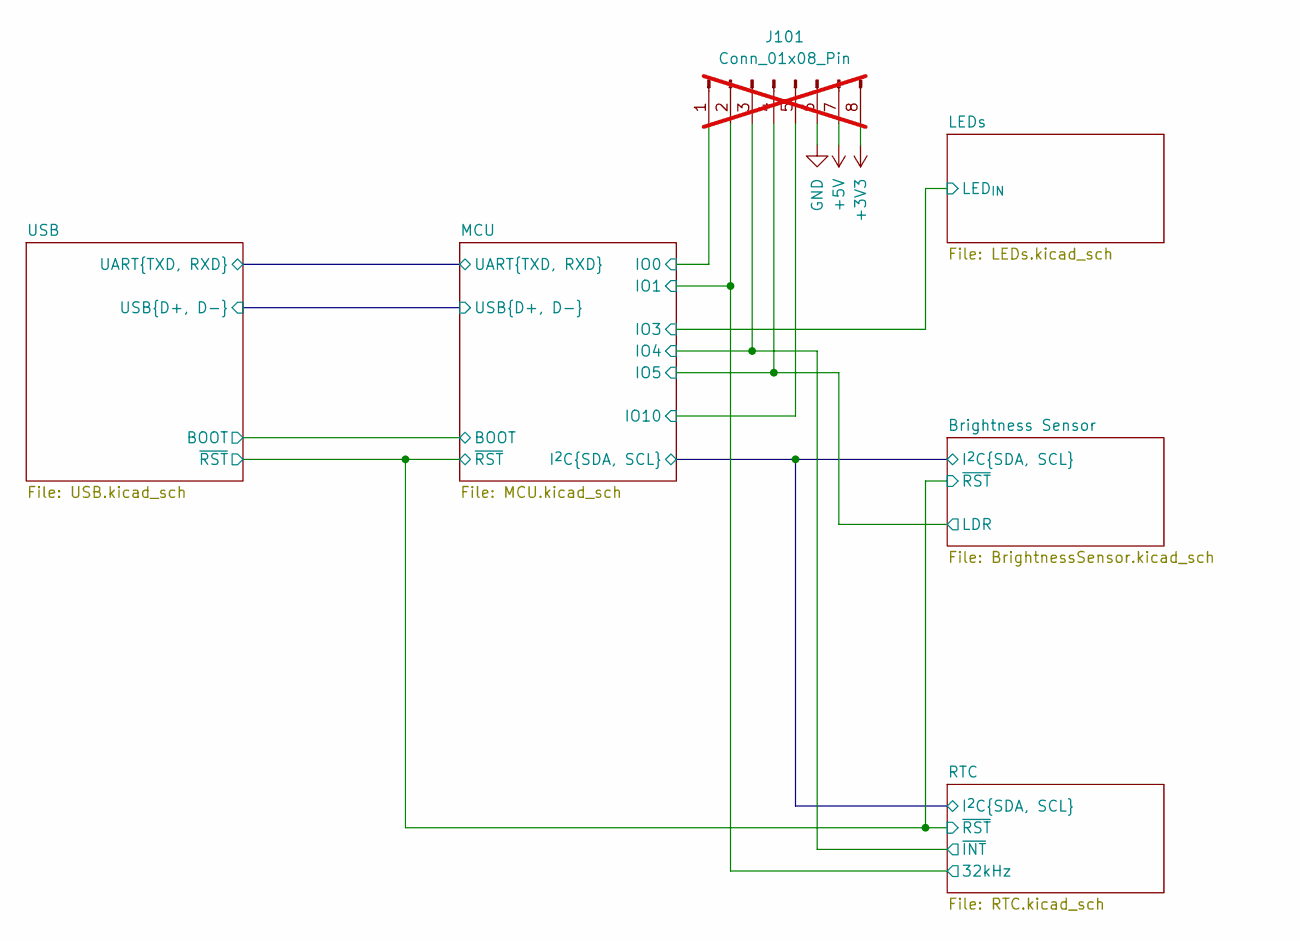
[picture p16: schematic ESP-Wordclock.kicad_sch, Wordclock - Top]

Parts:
J101: Conn_01x08_Pin; PinHeader_1x08_P2.54mm_Vertical; not fitted

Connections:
+3V3: J101.8; also elsewhere on the board
+5V: J101.7; also elsewhere on the board
/Brightness Sensor/LDR: J101.4; also elsewhere on the board
/MCU/IO0: J101.1; also elsewhere on the board
/MCU/IO1: J101.2; also elsewhere on the board
/MCU/IO4: J101.3; also elsewhere on the board
/MCU/IO10: J101.5; also elsewhere on the board
GND: J101.6; also elsewhere on the board

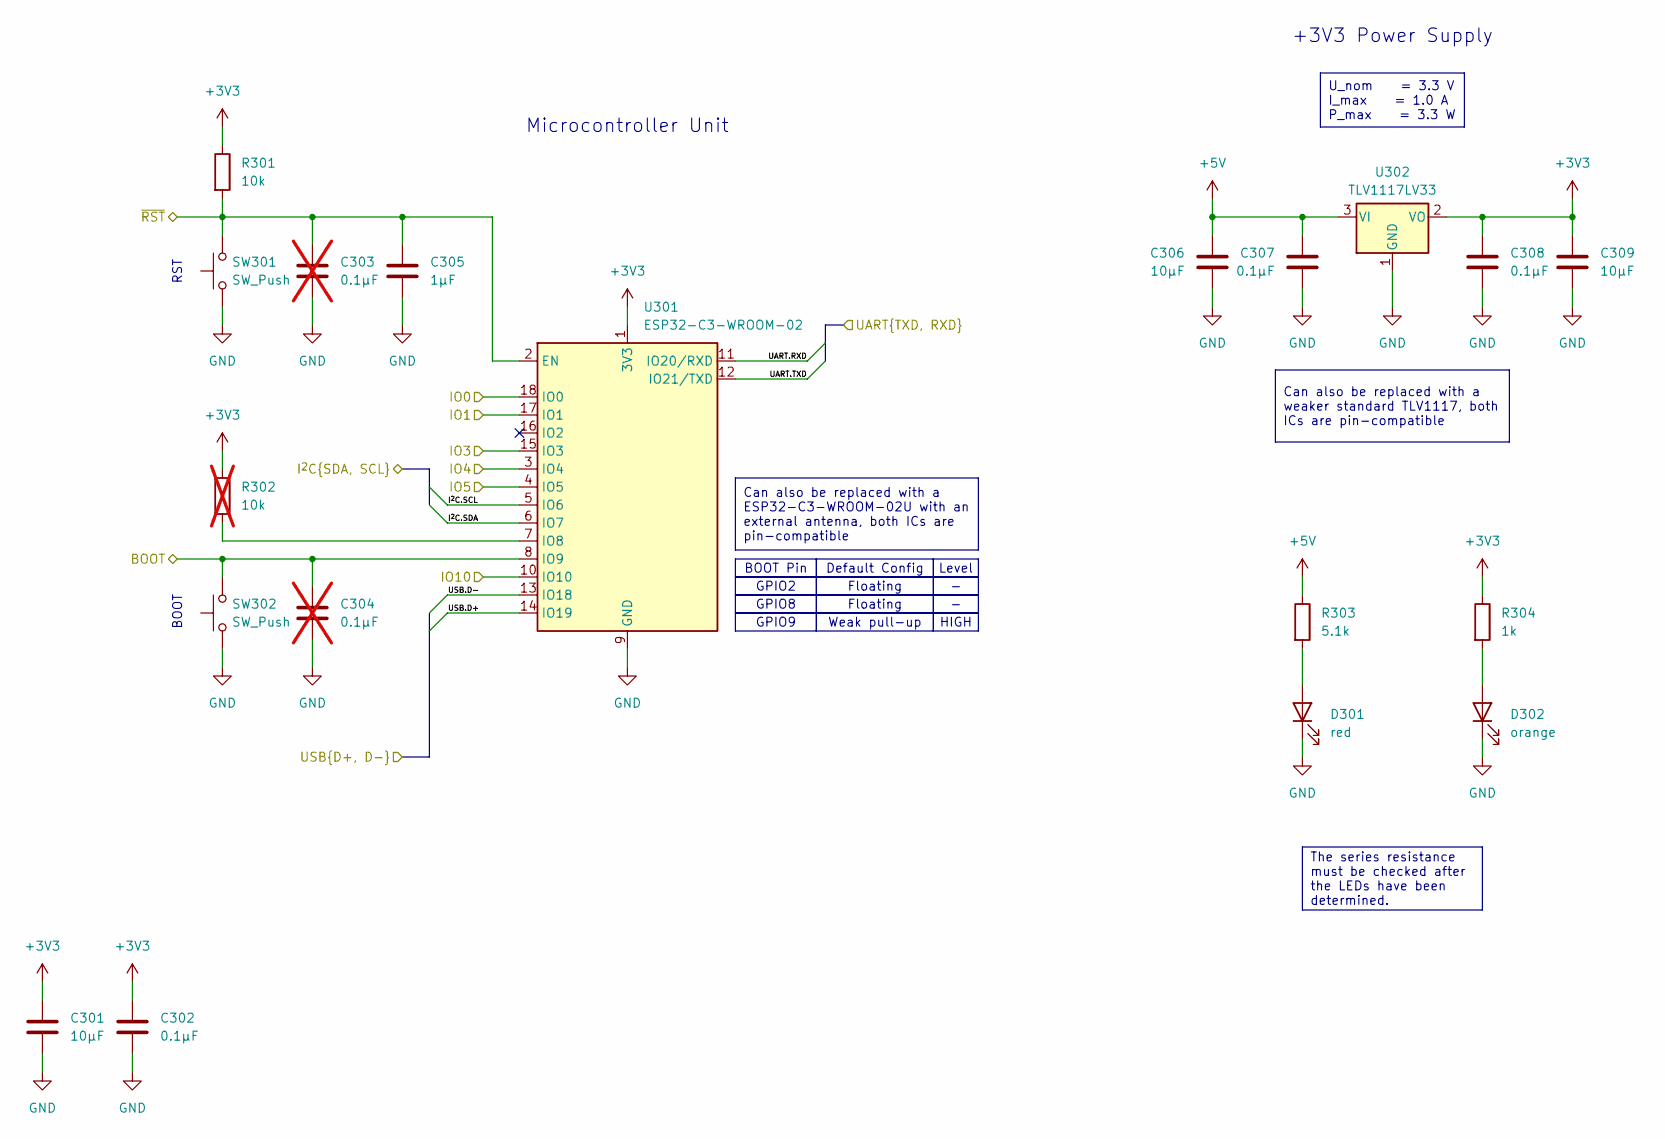
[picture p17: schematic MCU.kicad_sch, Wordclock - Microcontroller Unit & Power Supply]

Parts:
C301, C306, C309: 10µF; C_0805_2012Metric_Pad1.18x1.45mm_HandSolder; Manufacturer Part no. CL21A106KOQNNNE
C302, C307, C308: 0.1µF; C_0805_2012Metric_Pad1.18x1.45mm_HandSolder; Manufacturer Part no. CL21B104KCFNNNE
C303, C304: 0.1µF; C_0805_2012Metric_Pad1.18x1.45mm_HandSolder; Manufacturer Part no. CL21B104KCFNNNE; not fitted
C305: 1µF; C_0805_2012Metric_Pad1.18x1.45mm_HandSolder; Manufacturer Part no. CL21B105KPFNNNE
D301: red; LED_0805_2012Metric_Pad1.15x1.40mm_HandSolder; Manufacturer Part no. LTST-C171KRKT; LCSC C284871
D302: orange; LED_0805_2012Metric_Pad1.15x1.40mm_HandSolder; Manufacturer Part no. LTST-C170KFKT; LCSC C284931
R301: 10k; R_0805_2012Metric_Pad1.20x1.40mm_HandSolder; Manufacturer Part no. RC0805FR-0710KL
R302: 10k; R_0805_2012Metric_Pad1.20x1.40mm_HandSolder; Manufacturer Part no. RC0805FR-0710KL; not fitted
R303: 5.1k; R_0805_2012Metric_Pad1.20x1.40mm_HandSolder; Manufacturer Part no. RC0805FR-075K1L
R304: 1k; R_0805_2012Metric_Pad1.20x1.40mm_HandSolder; Manufacturer Part no. RC0805FR-071KL
SW301, SW302: SW_Push; SW_SPST_PTS810; Manufacturer Part no. PTS810 SJK 250 SMTR LFS; LCSC C221896
U301: ESP32-C3-WROOM-02; Manufacturer Part no. ESP32-C3-WROOM-02-N4; LCSC C2934560
U302: TLV1117LV33; SOT-223-3_TabPin2; Manufacturer Part no. TLV1117LV33DCYR; LCSC C15578

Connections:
+3V3: C301.1, C302.1, C308.1, C309.1, R301.1, R302.1, R304.1, U301.1 (3V3), U302.2 (VO); also elsewhere on the board
+5V: C306.1, C307.1, R303.1, U302.3 (VI); also elsewhere on the board
/Brightness Sensor/I^{2}C.SCL: U301.5 (IO6); also elsewhere on the board
/Brightness Sensor/I^{2}C.SDA: U301.6 (IO7); also elsewhere on the board
/Brightness Sensor/LDR: U301.4 (IO5); also elsewhere on the board
/Brightness Sensor/~RST: C303.1, C305.1, R301.2, SW301.2, U301.2 (EN); also elsewhere on the board
/LEDs/LED_{IN}: U301.15 (IO3); also elsewhere on the board
/MCU/BOOT: C304.1, SW302.2, U301.8 (IO9); also elsewhere on the board
/MCU/IO0: U301.18 (IO0); also elsewhere on the board
/MCU/IO1: U301.17 (IO1); also elsewhere on the board
/MCU/IO4: U301.3 (IO4); also elsewhere on the board
/MCU/IO10: U301.10 (IO10); also elsewhere on the board
/MCU/UART.RXD: U301.11 (IO20/RXD); also elsewhere on the board
/MCU/UART.TXD: U301.12 (IO21/TXD); also elsewhere on the board
/MCU/USB.D+: U301.14 (IO19); also elsewhere on the board
/MCU/USB.D-: U301.13 (IO18); also elsewhere on the board
GND: C301.2, C302.2, C303.2, C304.2, C305.2, C306.2, C307.2, C308.2, C309.2, D301.1 (K), D302.1 (K), SW301.1, SW302.1, U301.9 (GND), U301.19 (GND), U302.1 (GND); also elsewhere on the board
unnamed: D301.2 (A), R303.2
unnamed: D302.2 (A), R304.2
unnamed: R302.2, U301.7 (IO8)

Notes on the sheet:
Floating
BOOT Pin
GPIO8
Can also be replaced with a ESP32-C3-WROOM-02U with an external antenna, both ICs are pin-compatible
U_nom = 3.3 V I_max = 1.0 A P_max = 3.3 W
Default Config
Level
GPIO9
Weak pull-up
The series resistance must be checked after the LEDs have been determined.
HIGH
Can also be replaced with a weaker standard TLV1117, both ICs are pin-compatible
GPIO2
+3V3 Power Supply
Microcontroller Unit
RST
BOOT

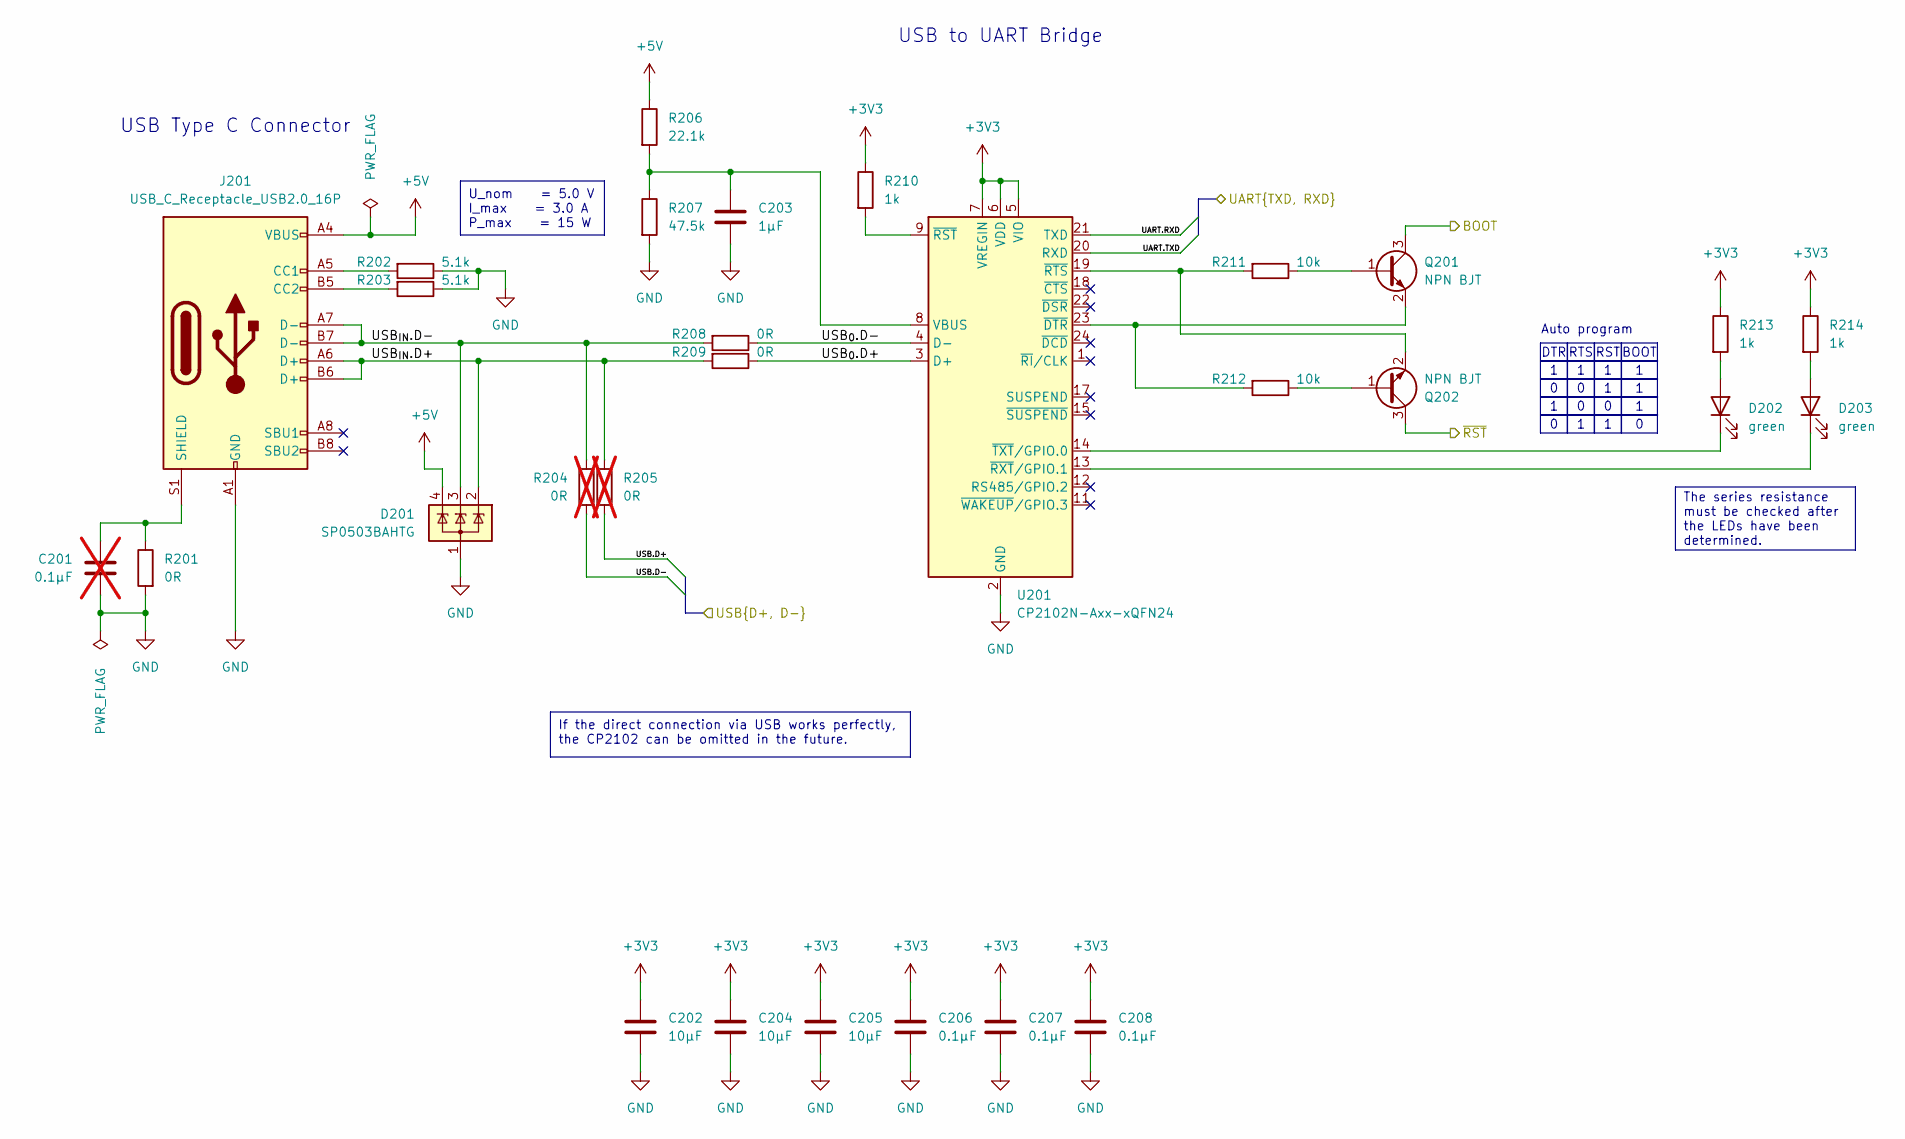
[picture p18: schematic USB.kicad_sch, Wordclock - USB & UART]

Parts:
C201: 0.1µF; C_0805_2012Metric_Pad1.18x1.45mm_HandSolder; Manufacturer Part no. CL21B104KCFNNNE; not fitted
C202, C204, C205: 10µF; C_0805_2012Metric_Pad1.18x1.45mm_HandSolder; Manufacturer Part no. CL21A106KOQNNNE
C203: 1µF; C_0805_2012Metric_Pad1.18x1.45mm_HandSolder; Manufacturer Part no. CL21B105KPFNNNE
C206, C207, C208: 0.1µF; C_0805_2012Metric_Pad1.18x1.45mm_HandSolder; Manufacturer Part no. CL21B104KCFNNNE
D201: SP0503BAHTG; SOT-143_Handsoldering; Manufacturer Part no. SP0503BAHTG; LCSC C7074
D202, D203: green; LED_0805_2012Metric_Pad1.15x1.40mm_HandSolder; Manufacturer Part no. LTST-C171GKT; LCSC C913075
J201: USB_C_Receptacle_USB2.0_16P; USB_C_Receptacle_GCT_USB4105-xx-A_16P_TopMnt_Horizontal; Manufacturer Part no. USB4105-GF-A; LCSC C3020560
Q201, Q202: NPN BJT; SOT-23_Handsoldering; LCSC C49581
R201, R208, R209: 0R; R_0805_2012Metric_Pad1.20x1.40mm_HandSolder; Manufacturer Part no. RC0805JR-070RL
R202, R203: 5.1k; R_0805_2012Metric_Pad1.20x1.40mm_HandSolder; Manufacturer Part no. RC0805FR-075K1L
R204, R205: 0R; R_0805_2012Metric_Pad1.20x1.40mm_HandSolder; Manufacturer Part no. RC0805JR-070RL; not fitted
R206: 22.1k; R_0805_2012Metric_Pad1.20x1.40mm_HandSolder; Manufacturer Part no. RC0805FR-0722K1L; LCSC C17552
R207: 47.5k; R_0805_2012Metric_Pad1.20x1.40mm_HandSolder; Manufacturer Part no. RC0805FR-0747K5L; LCSC C26011
R210, R213, R214: 1k; R_0805_2012Metric_Pad1.20x1.40mm_HandSolder; Manufacturer Part no. RC0805FR-071KL
R211, R212: 10k; R_0805_2012Metric_Pad1.20x1.40mm_HandSolder; Manufacturer Part no. RC0805FR-0710KL
U201: CP2102N-Axx-xQFN24; QFN-24-1EP_4x4mm_P0.5mm_EP2.6x2.6mm_ThermalVias; Manufacturer Part no. CP2102N-A02-GQFN24R; LCSC C969151

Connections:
+3V3: C202.1, C204.1, C205.1, C206.1, C207.1, C208.1, R210.1, R213.1, R214.1, U201.5 (VIO), U201.6 (VDD), U201.7 (VREGIN); also elsewhere on the board
+5V: D201.4 (K), J201.A4 (VBUS), J201.A9 (VBUS), J201.B4 (VBUS), J201.B9 (VBUS), R206.1; also elsewhere on the board
/Brightness Sensor/~RST: Q202.3 (C); also elsewhere on the board
/MCU/BOOT: Q201.3 (C); also elsewhere on the board
/MCU/UART.RXD: U201.21 (TXD); also elsewhere on the board
/MCU/UART.TXD: U201.20 (RXD); also elsewhere on the board
/MCU/USB.D+: R205.2; also elsewhere on the board
/MCU/USB.D-: R204.2; also elsewhere on the board
/USB/USB_{0}.D+: R209.1, U201.3 (D+)
/USB/USB_{0}.D-: R208.1, U201.4 (D-)
/USB/USB_{IN}.D+: D201.2 (K), J201.A6 (D+), J201.B6 (D+), R205.1, R209.2
/USB/USB_{IN}.D-: D201.3 (K), J201.A7 (D-), J201.B7 (D-), R204.1, R208.2
GND: C201.2, C202.2, C203.2, C204.2, C205.2, C206.2, C207.2, C208.2, D201.1 (A), J201.A1 (GND), J201.A12 (GND), J201.B1 (GND), J201.B12 (GND), R201.2, R202.1, R203.1, R207.2, U201.2 (GND), U201.25 (GND); also elsewhere on the board
unnamed: D202.2 (A), R213.2
unnamed: D202.1 (K), U201.14 (~TXT/GPIO.0)
unnamed: D203.2 (A), R214.2
unnamed: D203.1 (K), U201.13 (~RXT/GPIO.1)
unnamed: J201.A5 (CC1), R202.2
unnamed: J201.B5 (CC2), R203.2
unnamed: C201.1, J201.S1 (SHIELD), R201.1
unnamed: Q201.1 (B), R211.1
unnamed: Q201.2 (E), R212.2, U201.23 (~DTR)
unnamed: Q202.1 (B), R212.1
unnamed: Q202.2 (E), R211.2, U201.19 (~RTS)
unnamed: C203.1, R206.2, R207.1, U201.8 (VBUS)
unnamed: R210.2, U201.9 (~RST)

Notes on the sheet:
The series resistance must be checked after the LEDs have been determined.
DTR
RST
RTS
U_nom = 5.0 V I_max = 3.0 A P_max = 15 W
BOOT
If the direct connection via USB works perfectly, the CP2102 can be omitted in the future.
USB Type C Connector
Auto program
USB to UART Bridge

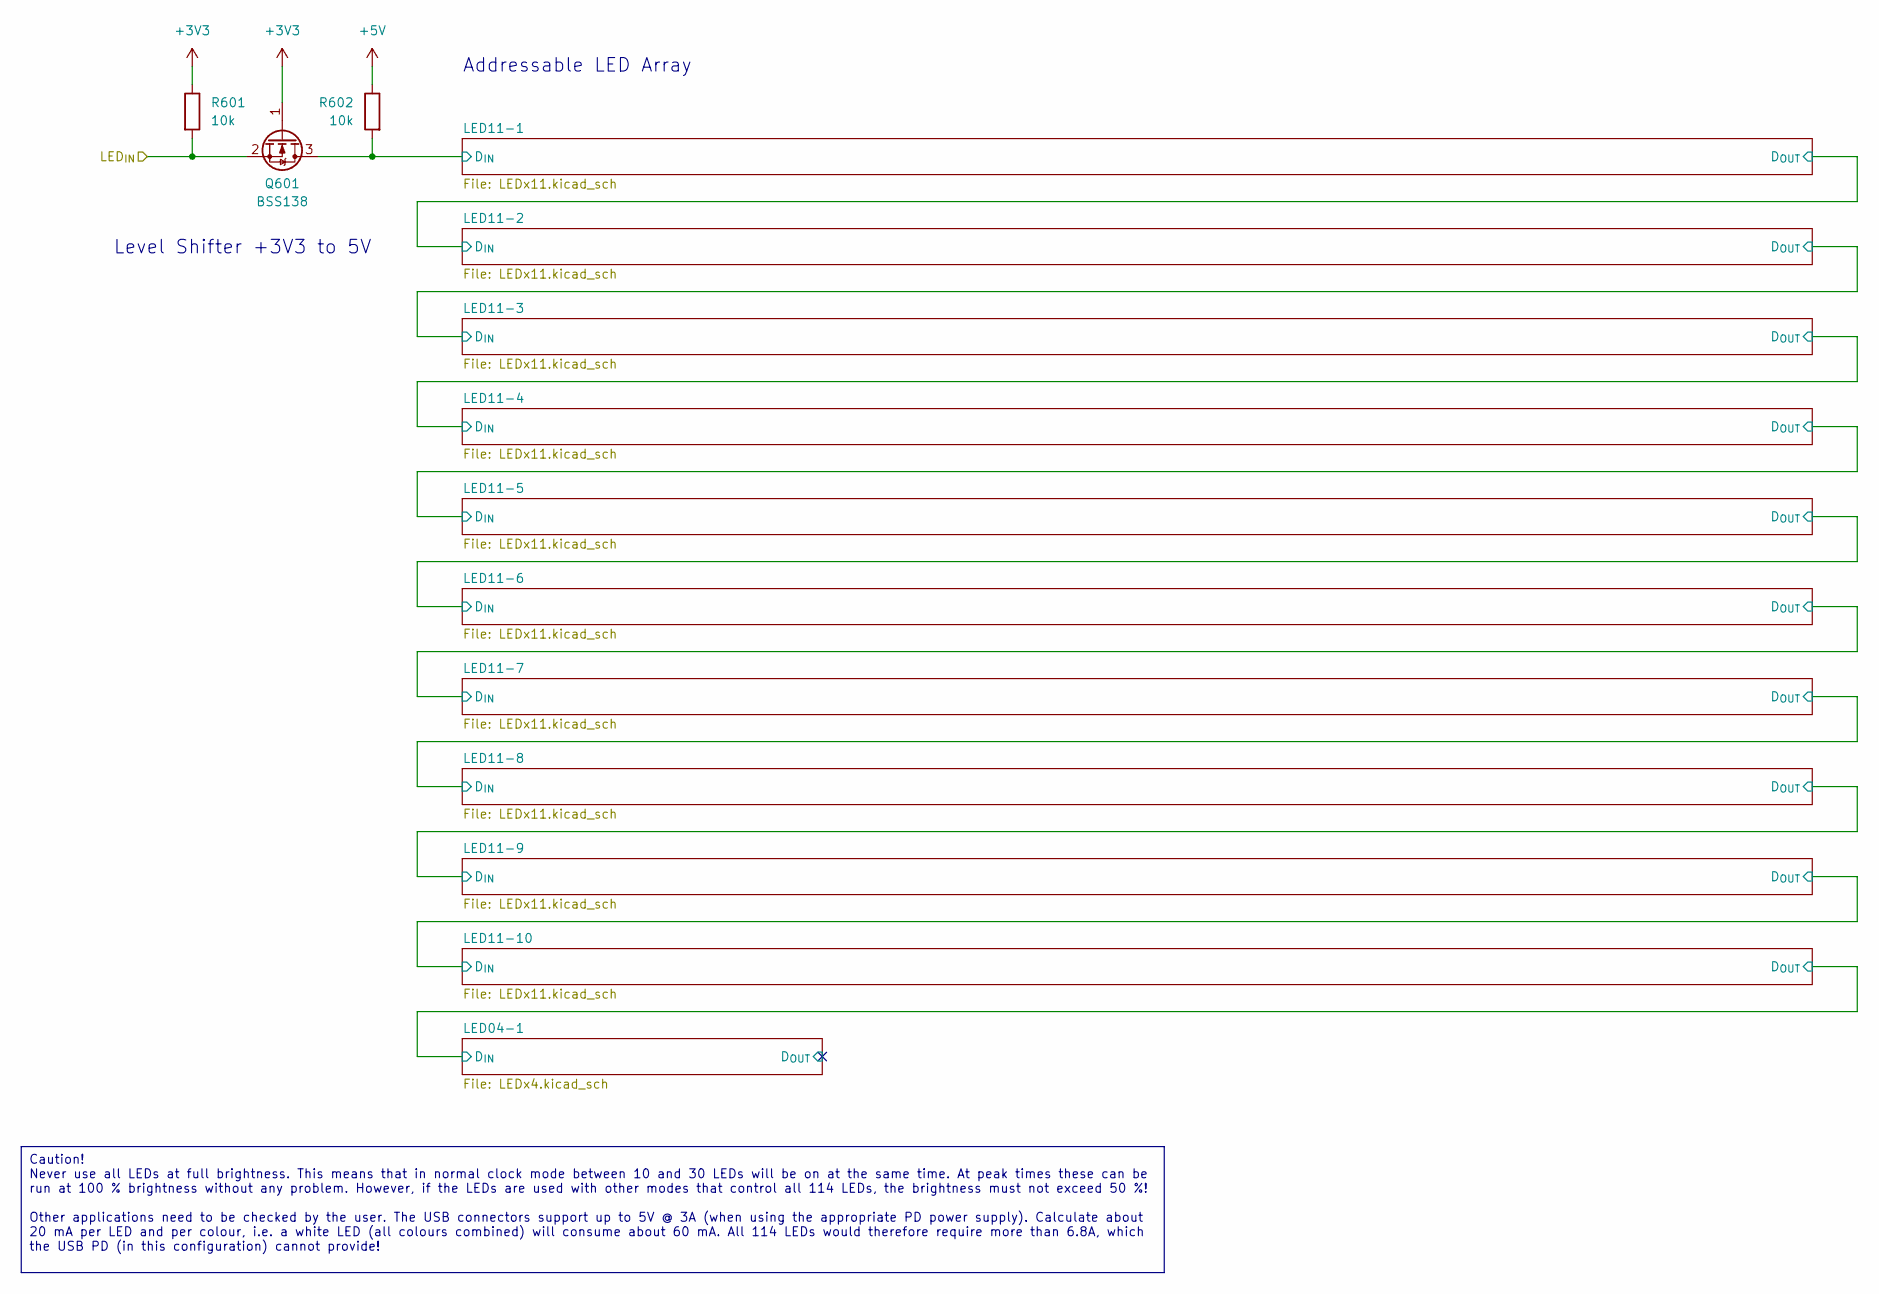
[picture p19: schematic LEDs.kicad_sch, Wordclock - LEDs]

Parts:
Q601: BSS138; SOT-23_Handsoldering; Manufacturer Part no. BSS138; LCSC C518792
R601, R602: 10k; R_0805_2012Metric_Pad1.20x1.40mm_HandSolder; Manufacturer Part no. RC0805FR-0710KL

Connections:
+3V3: Q601.1 (G), R601.1; also elsewhere on the board
+5V: R602.1; also elsewhere on the board
/LEDs/LED11-1/D_{IN}: Q601.3 (D), R602.2; also elsewhere on the board
/LEDs/LED_{IN}: Q601.2 (S), R601.2; also elsewhere on the board

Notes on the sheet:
Caution! Never use all LEDs at full brightness. This means that in normal clock mode between 10 and 30 LEDs will be on at the same time. At peak times these can be run at 100 % brightness without any problem. However, if the LEDs are used with other modes that control all 114 LEDs, the brightness m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
Level Shifter +3V3 to 5V
Addressable LED Array

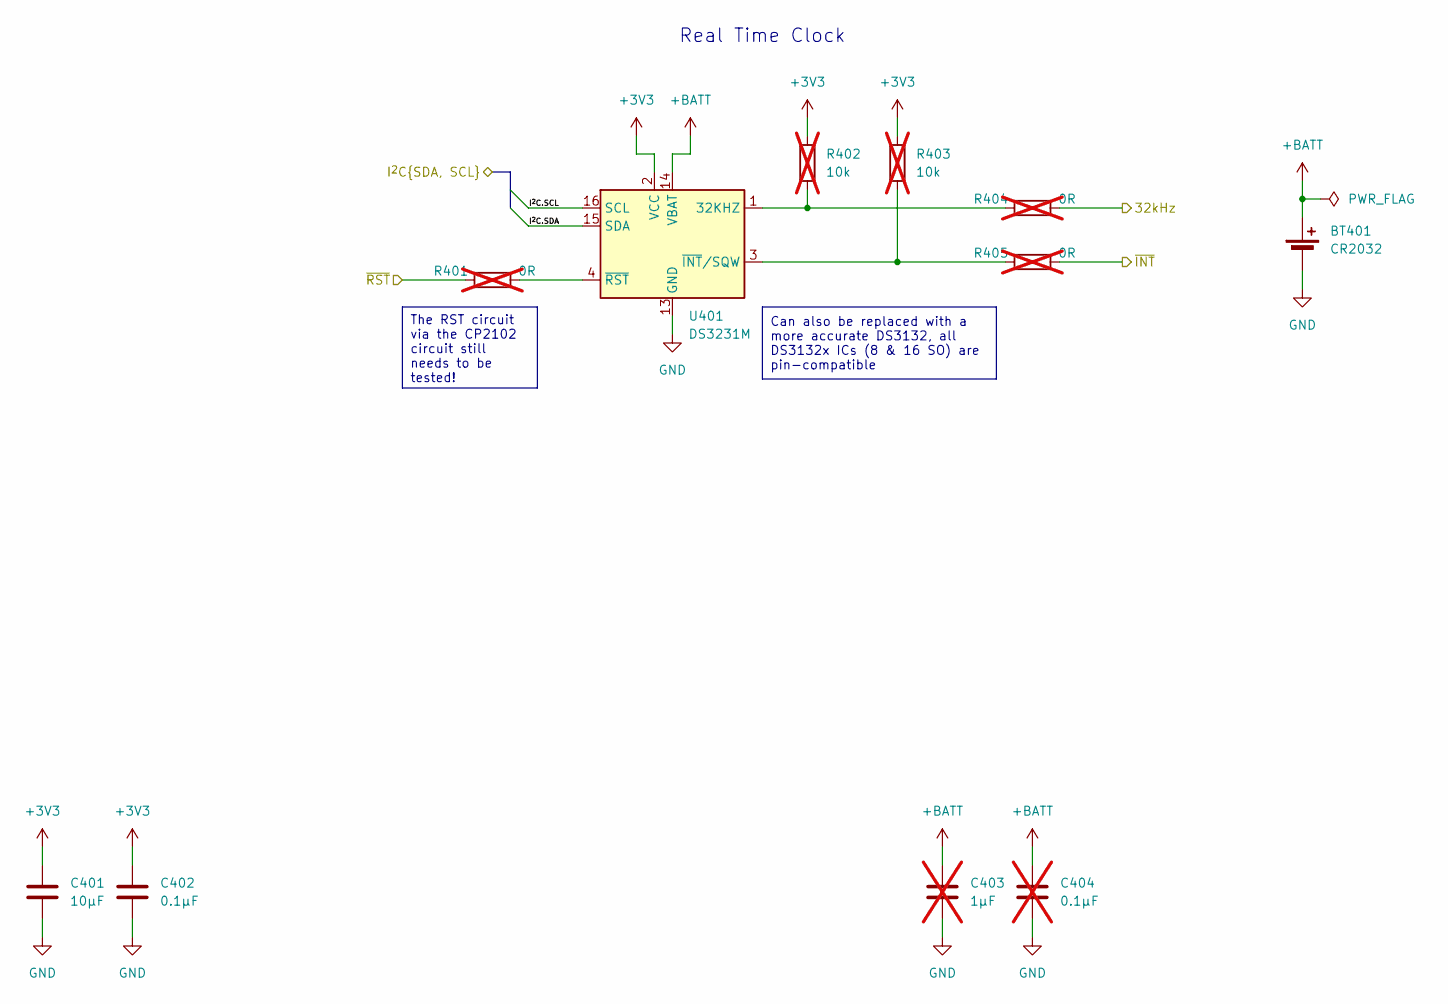
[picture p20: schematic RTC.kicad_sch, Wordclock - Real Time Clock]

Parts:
BT401: CR2032; BatteryHolder_Keystone_3002_1x2032; Manufacturer Part no. 2898; LCSC C6379018
C401: 10µF; C_0805_2012Metric_Pad1.18x1.45mm_HandSolder; Manufacturer Part no. CL21A106KOQNNNE
C402: 0.1µF; C_0805_2012Metric_Pad1.18x1.45mm_HandSolder; Manufacturer Part no. CL21B104KCFNNNE
C403: 1µF; C_0805_2012Metric_Pad1.18x1.45mm_HandSolder; Manufacturer Part no. CL21B105KPFNNNE; not fitted
C404: 0.1µF; C_0805_2012Metric_Pad1.18x1.45mm_HandSolder; Manufacturer Part no. CL21B104KCFNNNE; not fitted
R401, R404, R405: 0R; R_0805_2012Metric_Pad1.20x1.40mm_HandSolder; Manufacturer Part no. RC0805JR-070RL; not fitted
R402, R403: 10k; R_0805_2012Metric_Pad1.20x1.40mm_HandSolder; Manufacturer Part no. RC0805FR-0710KL; not fitted
U401: DS3231M; SOIC-16W_7.5x10.3mm_P1.27mm; Manufacturer Part no. DS3231M+TRL; LCSC C107410

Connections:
+3V3: C401.1, C402.1, R402.1, R403.1, U401.2 (VCC); also elsewhere on the board
+BATT: BT401.1 (+), C403.1, C404.1, U401.14 (VBAT)
/Brightness Sensor/I^{2}C.SCL: U401.16 (SCL); also elsewhere on the board
/Brightness Sensor/I^{2}C.SDA: U401.15 (SDA); also elsewhere on the board
/Brightness Sensor/~RST: R401.2; also elsewhere on the board
/MCU/IO1: R404.1; also elsewhere on the board
/MCU/IO4: R405.1; also elsewhere on the board
GND: BT401.2 (-), C401.2, C402.2, C403.2, C404.2, U401.5 (GND), U401.6 (GND), U401.7 (GND), U401.8 (GND), U401.9 (GND), U401.10 (GND), U401.11 (GND), U401.12 (GND), U401.13 (GND); also elsewhere on the board
unnamed: R402.2, R404.2, U401.1 (32KHZ)
unnamed: R403.2, R405.2, U401.3 (~INT/SQW)
unnamed: R401.1, U401.4 (~RST)

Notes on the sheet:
Can also be replaced with a more accurate DS3132, all DS3132x ICs (8 & 16 SO) are pin-compatible
The RST circuit via the CP2102 circuit still needs to be tested!
Real Time Clock

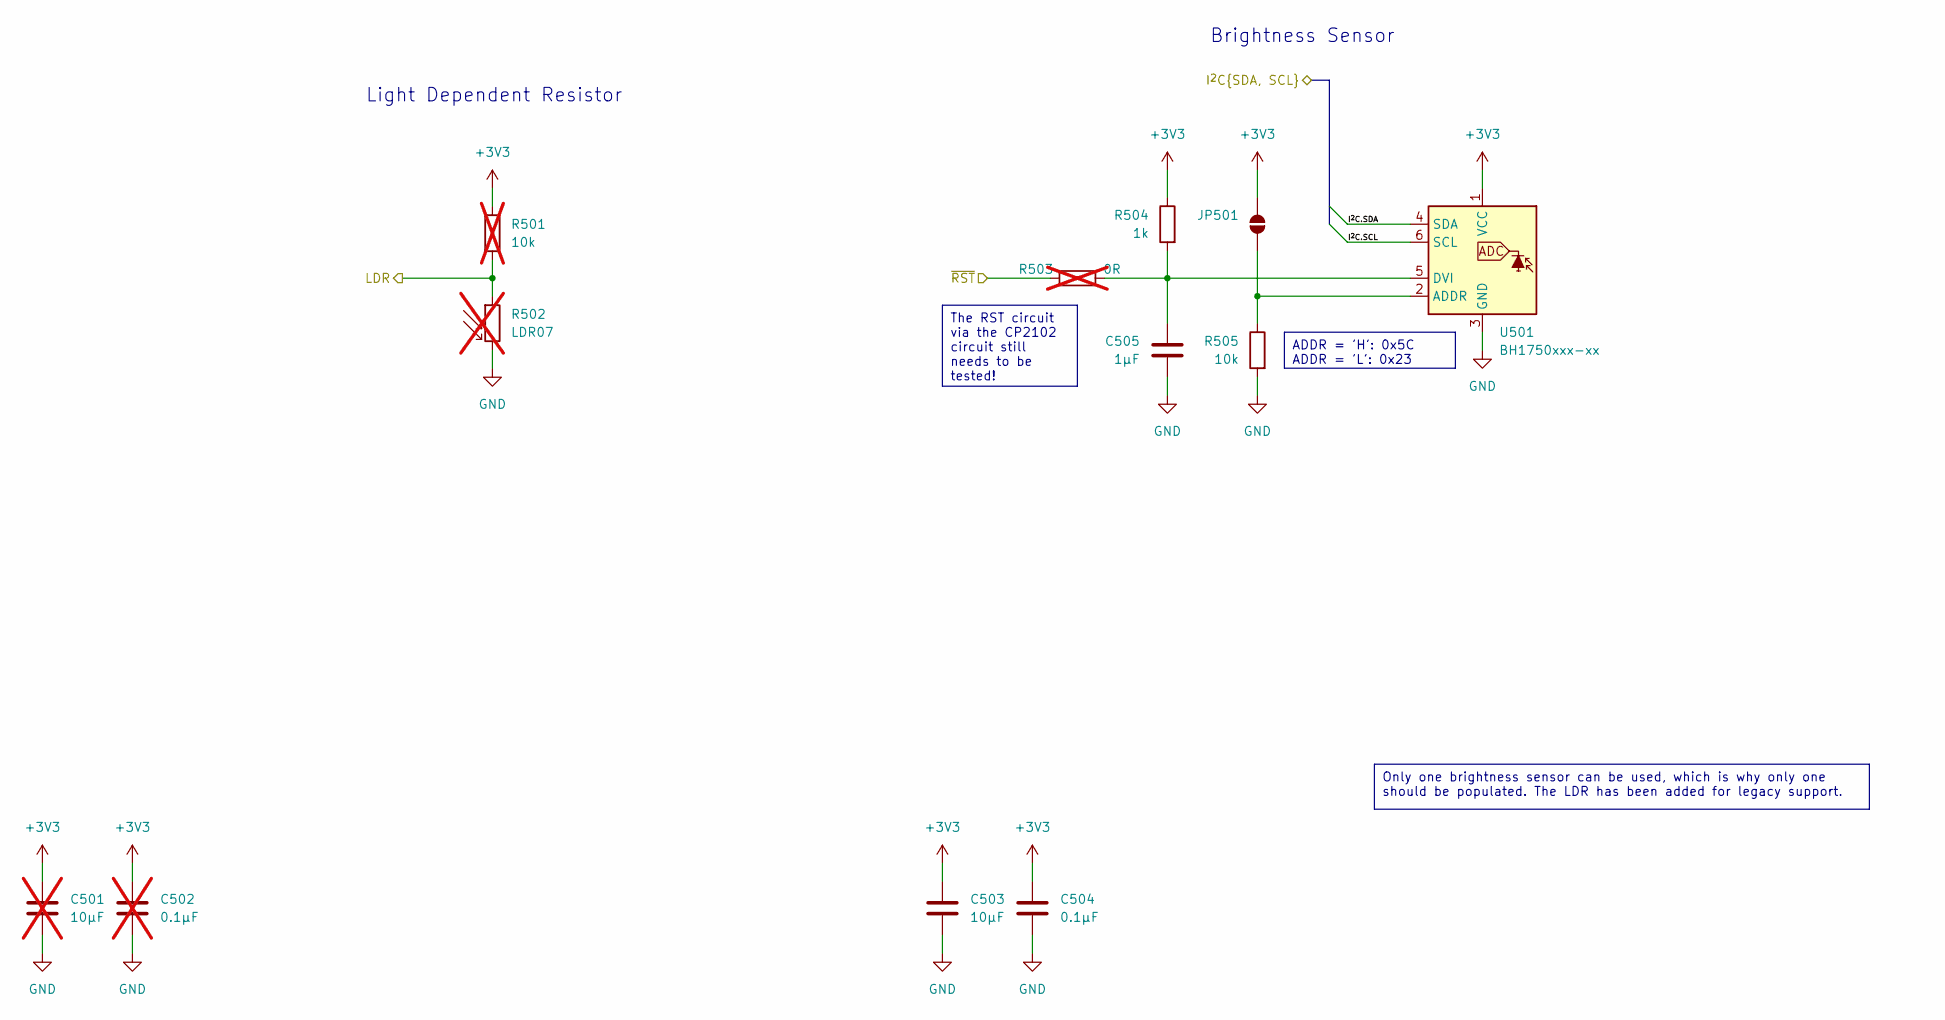
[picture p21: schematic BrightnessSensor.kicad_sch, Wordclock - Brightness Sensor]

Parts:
C501: 10µF; C_0805_2012Metric_Pad1.18x1.45mm_HandSolder; Manufacturer Part no. CL21A106KOQNNNE; not fitted
C502: 0.1µF; C_0805_2012Metric_Pad1.18x1.45mm_HandSolder; Manufacturer Part no. CL21B104KCFNNNE; not fitted
C503: 10µF; C_0805_2012Metric_Pad1.18x1.45mm_HandSolder; Manufacturer Part no. CL21A106KOQNNNE
C504: 0.1µF; C_0805_2012Metric_Pad1.18x1.45mm_HandSolder; Manufacturer Part no. CL21B104KCFNNNE
C505: 1µF; C_0805_2012Metric_Pad1.18x1.45mm_HandSolder; Manufacturer Part no. CL21B105KPFNNNE
JP501: SolderJumper_2_Open; SolderJumper-2_P1.3mm_Open_RoundedPad1.0x1.5mm
R501: 10k; R_0805_2012Metric_Pad1.20x1.40mm_HandSolder; Manufacturer Part no. RC0805FR-0710KL; not fitted
R502: LDR07; R_LDR_5.1x4.3mm_P3.4mm_Vertical; not fitted
R503: 0R; R_0805_2012Metric_Pad1.20x1.40mm_HandSolder; Manufacturer Part no. RC0805JR-070RL; not fitted
R504: 1k; R_0805_2012Metric_Pad1.20x1.40mm_HandSolder; Manufacturer Part no. RC0805FR-071KL
R505: 10k; R_0805_2012Metric_Pad1.20x1.40mm_HandSolder; Manufacturer Part no. RC0805FR-0710KL
U501: BH1750xxx-xx; HVSOF6; Manufacturer Part no. BH1750FVI-TR; LCSC C78960

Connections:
+3V3: C501.1, C502.1, C503.1, C504.1, JP501.2 (B), R501.1, R504.1, U501.1 (VCC); also elsewhere on the board
/Brightness Sensor/I^{2}C.SCL: U501.6 (SCL); also elsewhere on the board
/Brightness Sensor/I^{2}C.SDA: U501.4 (SDA); also elsewhere on the board
/Brightness Sensor/LDR: R501.2, R502.1; also elsewhere on the board
/Brightness Sensor/~RST: R503.2; also elsewhere on the board
GND: C501.2, C502.2, C503.2, C504.2, C505.2, R502.2, R505.2, U501.3 (GND); also elsewhere on the board
unnamed: JP501.1 (A), R505.1, U501.2 (ADDR)
unnamed: C505.1, R503.1, R504.2, U501.5 (DVI)

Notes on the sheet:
Only one brightness sensor can be used, which is why only one should be populated. The LDR has been added for legacy support.
The RST circuit via the CP2102 circuit still needs to be tested!
ADDR = 'H': 0x5C ADDR = 'L': 0x23
Brightness Sensor
Light Dependent Resistor

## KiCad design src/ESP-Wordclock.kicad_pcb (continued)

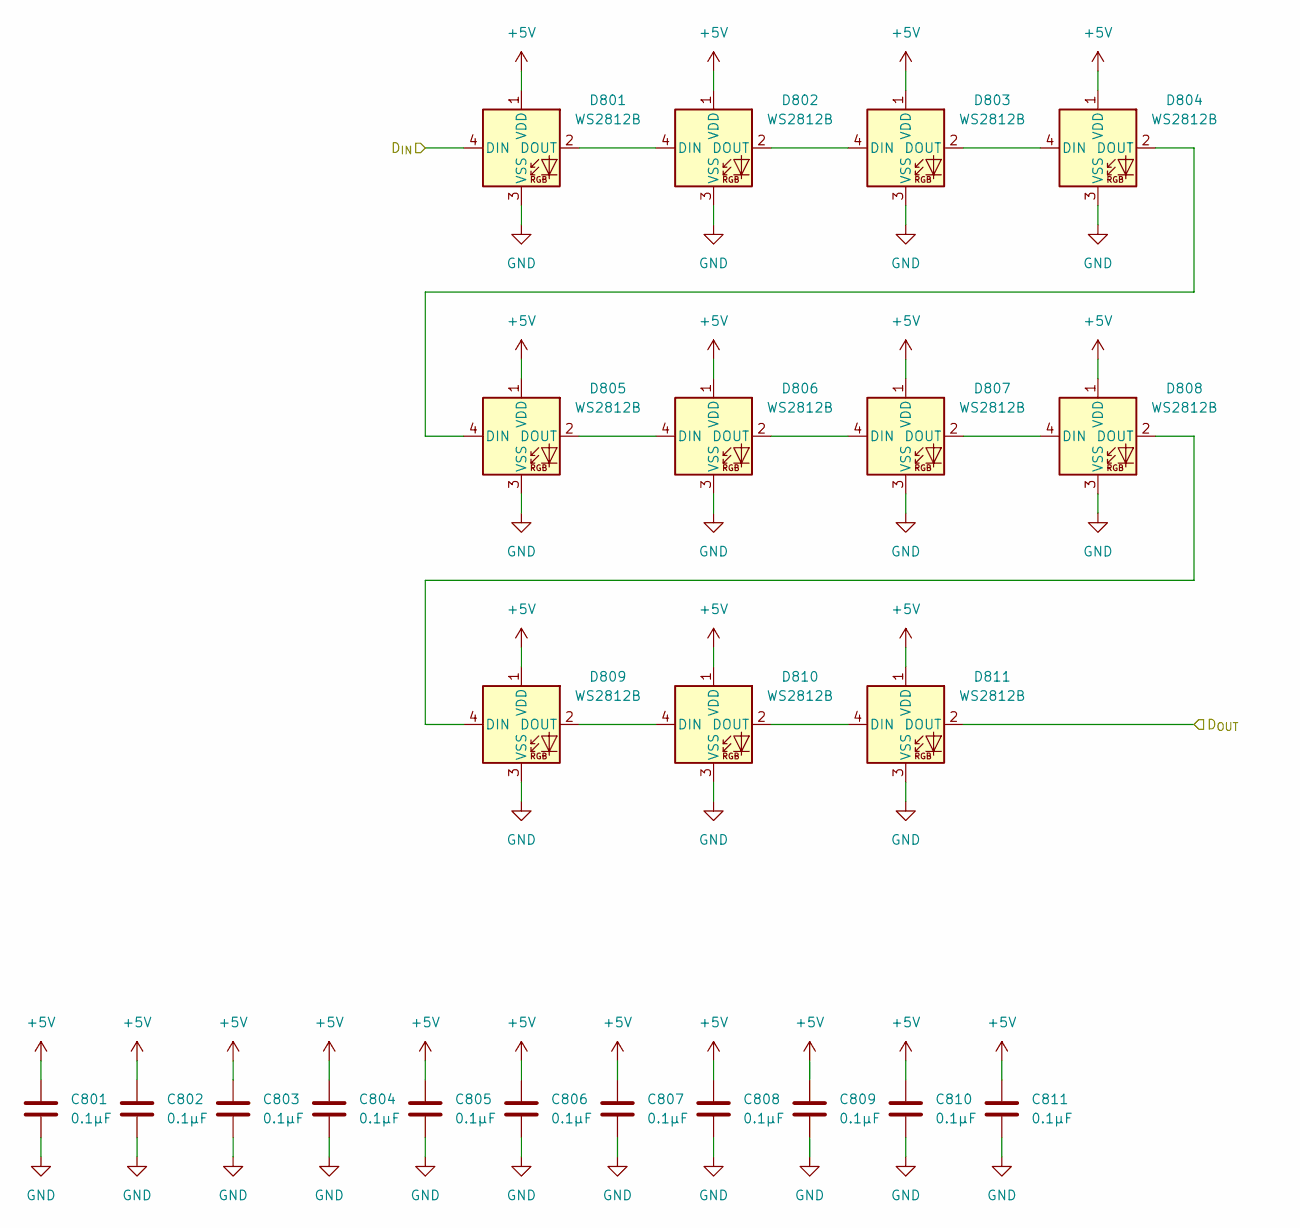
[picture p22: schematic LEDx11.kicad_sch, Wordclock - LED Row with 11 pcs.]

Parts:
C801, C802, C803, C804, C805, C806, C807, C808, C809, C810, C811: 0.1µF; C_0805_2012Metric_Pad1.18x1.45mm_HandSolder; Manufacturer Part no. CL21B104KCFNNNE
D801, D802, D803, D804, D805, D806, D807, D808, D809, D810, D811: WS2812B; LED_WS2812B_PLCC4_5.0x5.0mm_P3.2mm; Manufacturer Part no. WS2812B; LCSC C22461793

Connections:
+5V: C801.1, C802.1, C803.1, C804.1, C805.1, C806.1, C807.1, C808.1, C809.1, C810.1, C811.1, D801.1 (VDD), D802.1 (VDD), D803.1 (VDD), D804.1 (VDD), D805.1 (VDD), D806.1 (VDD), D807.1 (VDD), D808.1 (VDD), D809.1 (VDD), D810.1 (VDD), D811.1 (VDD); also elsewhere on the board
/LEDs/LED11-1/D_{IN}: D801.4 (DIN); also elsewhere on the board
/LEDs/LED11-1/D_{OUT}: D811.2 (DOUT); also elsewhere on the board
GND: C801.2, C802.2, C803.2, C804.2, C805.2, C806.2, C807.2, C808.2, C809.2, C810.2, C811.2, D801.3 (VSS), D802.3 (VSS), D803.3 (VSS), D804.3 (VSS), D805.3 (VSS), D806.3 (VSS), D807.3 (VSS), D808.3 (VSS), D809.3 (VSS), D810.3 (VSS), D811.3 (VSS); also elsewhere on the board
unnamed: D801.2 (DOUT), D802.4 (DIN)
unnamed: D802.2 (DOUT), D803.4 (DIN)
unnamed: D803.2 (DOUT), D804.4 (DIN)
unnamed: D804.2 (DOUT), D805.4 (DIN)
unnamed: D805.2 (DOUT), D806.4 (DIN)
unnamed: D806.2 (DOUT), D807.4 (DIN)
unnamed: D807.2 (DOUT), D808.4 (DIN)
unnamed: D808.2 (DOUT), D809.4 (DIN)
unnamed: D809.2 (DOUT), D810.4 (DIN)
unnamed: D810.2 (DOUT), D811.4 (DIN)

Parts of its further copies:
C901, C902, C903, C904, C905, C906, C907, C908, C909, C910, C911, C1001, C1002, C1003, C1004, C1005, C1006, C1007, C1008, C1009, C1010, C1011, C1101, C1102, C1103, C1104, C1105, C1106, C1107, C1108, C1109, C1110, C1111, C1201, C1202, C1203, C1204, C1205, C1206, C1207, C1208, C1209, C1210, C1211, C1301, C1302, C1303, C1304, C1305, C1306, C1307, C1308, C1309, C1310, C1311, C1401, C1402, C1403, C1404, C1405, C1406, C1407, C1408, C1409, C1410, C1411, C1501, C1502, C1503, C1504, C1505, C1506, C1507, C1508, C1509, C1510, C1511, C1601, C1602, C1603, C1604, C1605, C1606, C1607, C1608, C1609, C1610, C1611, C1701, C1702, C1703, C1704, C1705, C1706, C1707, C1708, C1709, C1710, C1711: 0.1µF; C_0805_2012Metric_Pad1.18x1.45mm_HandSolder; Manufacturer Part no. CL21B104KCFNNNE
D901, D902, D903, D904, D905, D906, D907, D908, D909, D910, D911, D1001, D1002, D1003, D1004, D1005, D1006, D1007, D1008, D1009, D1010, D1011, D1101, D1102, D1103, D1104, D1105, D1106, D1107, D1108, D1109, D1110, D1111, D1201, D1202, D1203, D1204, D1205, D1206, D1207, D1208, D1209, D1210, D1211, D1301, D1302, D1303, D1304, D1305, D1306, D1307, D1308, D1309, D1310, D1311, D1401, D1402, D1403, D1404, D1405, D1406, D1407, D1408, D1409, D1410, D1411, D1501, D1502, D1503, D1504, D1505, D1506, D1507, D1508, D1509, D1510, D1511, D1601, D1602, D1603, D1604, D1605, D1606, D1607, D1608, D1609, D1610, D1611, D1701, D1702, D1703, D1704, D1705, D1706, D1707, D1708, D1709, D1710, D1711: WS2812B; LED_WS2812B_PLCC4_5.0x5.0mm_P3.2mm; Manufacturer Part no. WS2812B; LCSC C22461793

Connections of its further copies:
+5V: C901.1, C902.1, C903.1, C904.1, C905.1, C906.1, C907.1, C908.1, C909.1, C910.1, C911.1, C1001.1, C1002.1, C1003.1, C1004.1, C1005.1, C1006.1, C1007.1, C1008.1, C1009.1, C1010.1, C1011.1, C1101.1, C1102.1, C1103.1, C1104.1, C1105.1, C1106.1, C1107.1, C1108.1, C1109.1, C1110.1, C1111.1, C1201.1, C1202.1, C1203.1, C1204.1, C1205.1, C1206.1, C1207.1, C1208.1, C1209.1, C1210.1, C1211.1, C1301.1, C1302.1, C1303.1, C1304.1, C1305.1, C1306.1, C1307.1, C1308.1, C1309.1, C1310.1, C1311.1, C1401.1, C1402.1, C1403.1, C1404.1, C1405.1, C1406.1, C1407.1, C1408.1, C1409.1, C1410.1, C1411.1, C1501.1, C1502.1, C1503.1, C1504.1, C1505.1, C1506.1, C1507.1, C1508.1, C1509.1, C1510.1, C1511.1, C1601.1, C1602.1, C1603.1, C1604.1, C1605.1, C1606.1, C1607.1, C1608.1, C1609.1, C1610.1, C1611.1, C1701.1, C1702.1, C1703.1, C1704.1, C1705.1, C1706.1, C1707.1, C1708.1, C1709.1, C1710.1, C1711.1, D901.1 (VDD), D902.1 (VDD), D903.1 (VDD), D904.1 (VDD), D905.1 (VDD), D906.1 (VDD), D907.1 (VDD), D908.1 (VDD), D909.1 (VDD), D910.1 (VDD), D911.1 (VDD), D1001.1 (VDD), D1002.1 (VDD), D1003.1 (VDD), D1004.1 (VDD), D1005.1 (VDD), D1006.1 (VDD), D1007.1 (VDD), D1008.1 (VDD), D1009.1 (VDD), D1010.1 (VDD), D1011.1 (VDD), D1101.1 (VDD), D1102.1 (VDD), D1103.1 (VDD), D1104.1 (VDD), D1105.1 (VDD), D1106.1 (VDD), D1107.1 (VDD), D1108.1 (VDD), D1109.1 (VDD), D1110.1 (VDD), D1111.1 (VDD), D1201.1 (VDD), D1202.1 (VDD), D1203.1 (VDD), D1204.1 (VDD), D1205.1 (VDD), D1206.1 (VDD), D1207.1 (VDD), D1208.1 (VDD), D1209.1 (VDD), D1210.1 (VDD), D1211.1 (VDD), D1301.1 (VDD), D1302.1 (VDD), D1303.1 (VDD), D1304.1 (VDD), D1305.1 (VDD), D1306.1 (VDD), D1307.1 (VDD), D1308.1 (VDD), D1309.1 (VDD), D1310.1 (VDD), D1311.1 (VDD), D1401.1 (VDD), D1402.1 (VDD), D1403.1 (VDD), D1404.1 (VDD), D1405.1 (VDD), D1406.1 (VDD), D1407.1 (VDD), D1408.1 (VDD), D1409.1 (VDD), D1410.1 (VDD), D1411.1 (VDD), D1501.1 (VDD), D1502.1 (VDD), D1503.1 (VDD), D1504.1 (VDD), D1505.1 (VDD), D1506.1 (VDD), D1507.1 (VDD), D1508.1 (VDD), D1509.1 (VDD), D1510.1 (VDD), D1511.1 (VDD), D1601.1 (VDD), D1602.1 (VDD), D1603.1 (VDD), D1604.1 (VDD), D1605.1 (VDD), D1606.1 (VDD), D1607.1 (VDD), D1608.1 (VDD), D1609.1 (VDD), D1610.1 (VDD), D1611.1 (VDD), D1701.1 (VDD), D1702.1 (VDD), D1703.1 (VDD), D1704.1 (VDD), D1705.1 (VDD), D1706.1 (VDD), D1707.1 (VDD), D1708.1 (VDD), D1709.1 (VDD), D1710.1 (VDD), D1711.1 (VDD); also elsewhere on the board
/LEDs/LED04-1/D_{IN}: D1711.2 (DOUT); also elsewhere on the board
/LEDs/LED11-1/D_{OUT}: D901.4 (DIN); also elsewhere on the board
/LEDs/LED11-2/D_{OUT}: D911.2 (DOUT), D1001.4 (DIN)
/LEDs/LED11-3/D_{OUT}: D1011.2 (DOUT), D1101.4 (DIN)
/LEDs/LED11-4/D_{OUT}: D1111.2 (DOUT), D1201.4 (DIN)
/LEDs/LED11-5/D_{OUT}: D1211.2 (DOUT), D1301.4 (DIN)
/LEDs/LED11-6/D_{OUT}: D1311.2 (DOUT), D1401.4 (DIN)
/LEDs/LED11-7/D_{OUT}: D1411.2 (DOUT), D1501.4 (DIN)
/LEDs/LED11-8/D_{OUT}: D1511.2 (DOUT), D1601.4 (DIN)
/LEDs/LED11-10/D_{IN}: D1611.2 (DOUT), D1701.4 (DIN)
GND: C901.2, C902.2, C903.2, C904.2, C905.2, C906.2, C907.2, C908.2, C909.2, C910.2, C911.2, C1001.2, C1002.2, C1003.2, C1004.2, C1005.2, C1006.2, C1007.2, C1008.2, C1009.2, C1010.2, C1011.2, C1101.2, C1102.2, C1103.2, C1104.2, C1105.2, C1106.2, C1107.2, C1108.2, C1109.2, C1110.2, C1111.2, C1201.2, C1202.2, C1203.2, C1204.2, C1205.2, C1206.2, C1207.2, C1208.2, C1209.2, C1210.2, C1211.2, C1301.2, C1302.2, C1303.2, C1304.2, C1305.2, C1306.2, C1307.2, C1308.2, C1309.2, C1310.2, C1311.2, C1401.2, C1402.2, C1403.2, C1404.2, C1405.2, C1406.2, C1407.2, C1408.2, C1409.2, C1410.2, C1411.2, C1501.2, C1502.2, C1503.2, C1504.2, C1505.2, C1506.2, C1507.2, C1508.2, C1509.2, C1510.2, C1511.2, C1601.2, C1602.2, C1603.2, C1604.2, C1605.2, C1606.2, C1607.2, C1608.2, C1609.2, C1610.2, C1611.2, C1701.2, C1702.2, C1703.2, C1704.2, C1705.2, C1706.2, C1707.2, C1708.2, C1709.2, C1710.2, C1711.2, D901.3 (VSS), D902.3 (VSS), D903.3 (VSS), D904.3 (VSS), D905.3 (VSS), D906.3 (VSS), D907.3 (VSS), D908.3 (VSS), D909.3 (VSS), D910.3 (VSS), D911.3 (VSS), D1001.3 (VSS), D1002.3 (VSS), D1003.3 (VSS), D1004.3 (VSS), D1005.3 (VSS), D1006.3 (VSS), D1007.3 (VSS), D1008.3 (VSS), D1009.3 (VSS), D1010.3 (VSS), D1011.3 (VSS), D1101.3 (VSS), D1102.3 (VSS), D1103.3 (VSS), D1104.3 (VSS), D1105.3 (VSS), D1106.3 (VSS), D1107.3 (VSS), D1108.3 (VSS), D1109.3 (VSS), D1110.3 (VSS), D1111.3 (VSS), D1201.3 (VSS), D1202.3 (VSS), D1203.3 (VSS), D1204.3 (VSS), D1205.3 (VSS), D1206.3 (VSS), D1207.3 (VSS), D1208.3 (VSS), D1209.3 (VSS), D1210.3 (VSS), D1211.3 (VSS), D1301.3 (VSS), D1302.3 (VSS), D1303.3 (VSS), D1304.3 (VSS), D1305.3 (VSS), D1306.3 (VSS), D1307.3 (VSS), D1308.3 (VSS), D1309.3 (VSS), D1310.3 (VSS), D1311.3 (VSS), D1401.3 (VSS), D1402.3 (VSS), D1403.3 (VSS), D1404.3 (VSS), D1405.3 (VSS), D1406.3 (VSS), D1407.3 (VSS), D1408.3 (VSS), D1409.3 (VSS), D1410.3 (VSS), D1411.3 (VSS), D1501.3 (VSS), D1502.3 (VSS), D1503.3 (VSS), D1504.3 (VSS), D1505.3 (VSS), D1506.3 (VSS), D1507.3 (VSS), D1508.3 (VSS), D1509.3 (VSS), D1510.3 (VSS), D1511.3 (VSS), D1601.3 (VSS), D1602.3 (VSS), D1603.3 (VSS), D1604.3 (VSS), D1605.3 (VSS), D1606.3 (VSS), D1607.3 (VSS), D1608.3 (VSS), D1609.3 (VSS), D1610.3 (VSS), D1611.3 (VSS), D1701.3 (VSS), D1702.3 (VSS), D1703.3 (VSS), D1704.3 (VSS), D1705.3 (VSS), D1706.3 (VSS), D1707.3 (VSS), D1708.3 (VSS), D1709.3 (VSS), D1710.3 (VSS), D1711.3 (VSS); also elsewhere on the board
unnamed: D901.2 (DOUT), D902.4 (DIN)
unnamed: D902.2 (DOUT), D903.4 (DIN)
unnamed: D903.2 (DOUT), D904.4 (DIN)
unnamed: D904.2 (DOUT), D905.4 (DIN)
unnamed: D905.2 (DOUT), D906.4 (DIN)
unnamed: D906.2 (DOUT), D907.4 (DIN)
unnamed: D907.2 (DOUT), D908.4 (DIN)
unnamed: D908.2 (DOUT), D909.4 (DIN)
unnamed: D909.2 (DOUT), D910.4 (DIN)
unnamed: D910.2 (DOUT), D911.4 (DIN)
unnamed: D1001.2 (DOUT), D1002.4 (DIN)
unnamed: D1002.2 (DOUT), D1003.4 (DIN)
unnamed: D1003.2 (DOUT), D1004.4 (DIN)
unnamed: D1004.2 (DOUT), D1005.4 (DIN)
unnamed: D1005.2 (DOUT), D1006.4 (DIN)
unnamed: D1006.2 (DOUT), D1007.4 (DIN)
unnamed: D1007.2 (DOUT), D1008.4 (DIN)
unnamed: D1008.2 (DOUT), D1009.4 (DIN)
unnamed: D1009.2 (DOUT), D1010.4 (DIN)
unnamed: D1010.2 (DOUT), D1011.4 (DIN)
unnamed: D1101.2 (DOUT), D1102.4 (DIN)
unnamed: D1102.2 (DOUT), D1103.4 (DIN)
unnamed: D1103.2 (DOUT), D1104.4 (DIN)
unnamed: D1104.2 (DOUT), D1105.4 (DIN)
unnamed: D1105.2 (DOUT), D1106.4 (DIN)
unnamed: D1106.2 (DOUT), D1107.4 (DIN)
unnamed: D1107.2 (DOUT), D1108.4 (DIN)
unnamed: D1108.2 (DOUT), D1109.4 (DIN)
unnamed: D1109.2 (DOUT), D1110.4 (DIN)
unnamed: D1110.2 (DOUT), D1111.4 (DIN)
unnamed: D1201.2 (DOUT), D1202.4 (DIN)
unnamed: D1202.2 (DOUT), D1203.4 (DIN)
unnamed: D1203.2 (DOUT), D1204.4 (DIN)
unnamed: D1204.2 (DOUT), D1205.4 (DIN)
unnamed: D1205.2 (DOUT), D1206.4 (DIN)
unnamed: D1206.2 (DOUT), D1207.4 (DIN)
unnamed: D1207.2 (DOUT), D1208.4 (DIN)
unnamed: D1208.2 (DOUT), D1209.4 (DIN)
unnamed: D1209.2 (DOUT), D1210.4 (DIN)
unnamed: D1210.2 (DOUT), D1211.4 (DIN)
unnamed: D1301.2 (DOUT), D1302.4 (DIN)
unnamed: D1302.2 (DOUT), D1303.4 (DIN)
unnamed: D1303.2 (DOUT), D1304.4 (DIN)
unnamed: D1304.2 (DOUT), D1305.4 (DIN)
unnamed: D1305.2 (DOUT), D1306.4 (DIN)
unnamed: D1306.2 (DOUT), D1307.4 (DIN)
unnamed: D1307.2 (DOUT), D1308.4 (DIN)
unnamed: D1308.2 (DOUT), D1309.4 (DIN)
unnamed: D1309.2 (DOUT), D1310.4 (DIN)
unnamed: D1310.2 (DOUT), D1311.4 (DIN)
unnamed: D1401.2 (DOUT), D1402.4 (DIN)
unnamed: D1402.2 (DOUT), D1403.4 (DIN)
unnamed: D1403.2 (DOUT), D1404.4 (DIN)
unnamed: D1404.2 (DOUT), D1405.4 (DIN)
unnamed: D1405.2 (DOUT), D1406.4 (DIN)
unnamed: D1406.2 (DOUT), D1407.4 (DIN)
unnamed: D1407.2 (DOUT), D1408.4 (DIN)
unnamed: D1408.2 (DOUT), D1409.4 (DIN)
unnamed: D1409.2 (DOUT), D1410.4 (DIN)
unnamed: D1410.2 (DOUT), D1411.4 (DIN)
unnamed: D1501.2 (DOUT), D1502.4 (DIN)
unnamed: D1502.2 (DOUT), D1503.4 (DIN)
unnamed: D1503.2 (DOUT), D1504.4 (DIN)
unnamed: D1504.2 (DOUT), D1505.4 (DIN)
unnamed: D1505.2 (DOUT), D1506.4 (DIN)
unnamed: D1506.2 (DOUT), D1507.4 (DIN)
unnamed: D1507.2 (DOUT), D1508.4 (DIN)
unnamed: D1508.2 (DOUT), D1509.4 (DIN)
unnamed: D1509.2 (DOUT), D1510.4 (DIN)
unnamed: D1510.2 (DOUT), D1511.4 (DIN)
unnamed: D1601.2 (DOUT), D1602.4 (DIN)
unnamed: D1602.2 (DOUT), D1603.4 (DIN)
unnamed: D1603.2 (DOUT), D1604.4 (DIN)
unnamed: D1604.2 (DOUT), D1605.4 (DIN)
unnamed: D1605.2 (DOUT), D1606.4 (DIN)
unnamed: D1606.2 (DOUT), D1607.4 (DIN)
unnamed: D1607.2 (DOUT), D1608.4 (DIN)
unnamed: D1608.2 (DOUT), D1609.4 (DIN)
unnamed: D1609.2 (DOUT), D1610.4 (DIN)
unnamed: D1610.2 (DOUT), D1611.4 (DIN)
unnamed: D1701.2 (DOUT), D1702.4 (DIN)
unnamed: D1702.2 (DOUT), D1703.4 (DIN)
unnamed: D1703.2 (DOUT), D1704.4 (DIN)
unnamed: D1704.2 (DOUT), D1705.4 (DIN)
unnamed: D1705.2 (DOUT), D1706.4 (DIN)
unnamed: D1706.2 (DOUT), D1707.4 (DIN)
unnamed: D1707.2 (DOUT), D1708.4 (DIN)
unnamed: D1708.2 (DOUT), D1709.4 (DIN)
unnamed: D1709.2 (DOUT), D1710.4 (DIN)
unnamed: D1710.2 (DOUT), D1711.4 (DIN)

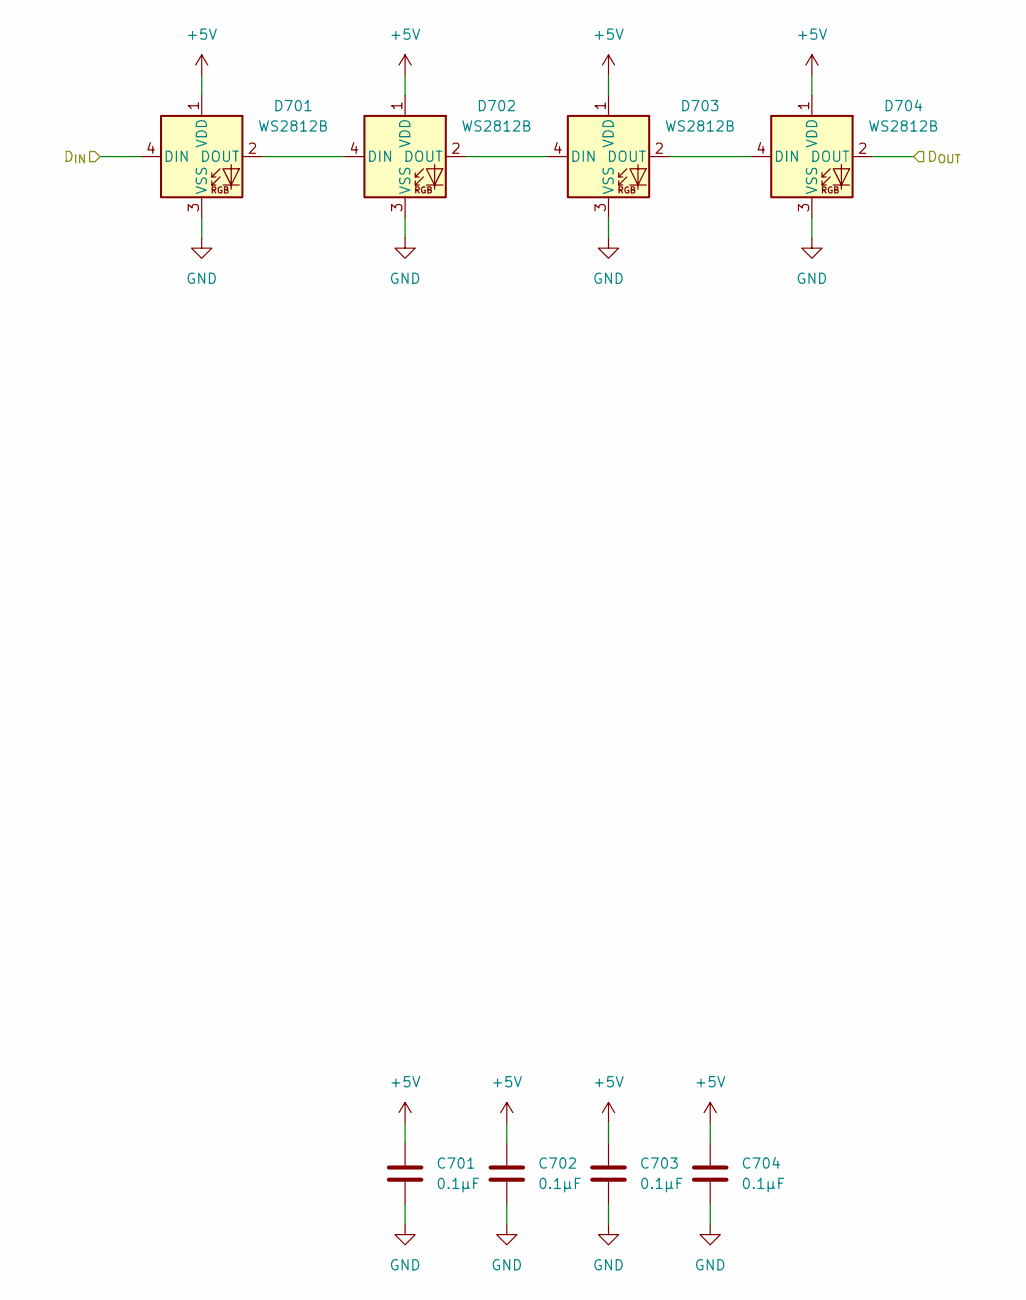
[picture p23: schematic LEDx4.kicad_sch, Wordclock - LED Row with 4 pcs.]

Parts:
C701, C702, C703, C704: 0.1µF; C_0805_2012Metric_Pad1.18x1.45mm_HandSolder; Manufacturer Part no. CL21B104KCFNNNE
D701, D702, D703, D704: WS2812B; LED_WS2812B_PLCC4_5.0x5.0mm_P3.2mm; Manufacturer Part no. WS2812B; LCSC C22461793

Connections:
+5V: C701.1, C702.1, C703.1, C704.1, D701.1 (VDD), D702.1 (VDD), D703.1 (VDD), D704.1 (VDD); also elsewhere on the board
/LEDs/LED04-1/D_{IN}: D701.4 (DIN); also elsewhere on the board
/LEDs/LED04-1/D_{OUT}: D704.2 (DOUT)
GND: C701.2, C702.2, C703.2, C704.2, D701.3 (VSS), D702.3 (VSS), D703.3 (VSS), D704.3 (VSS); also elsewhere on the board
unnamed: D701.2 (DOUT), D702.4 (DIN)
unnamed: D702.2 (DOUT), D703.4 (DIN)
unnamed: D703.2 (DOUT), D704.4 (DIN)

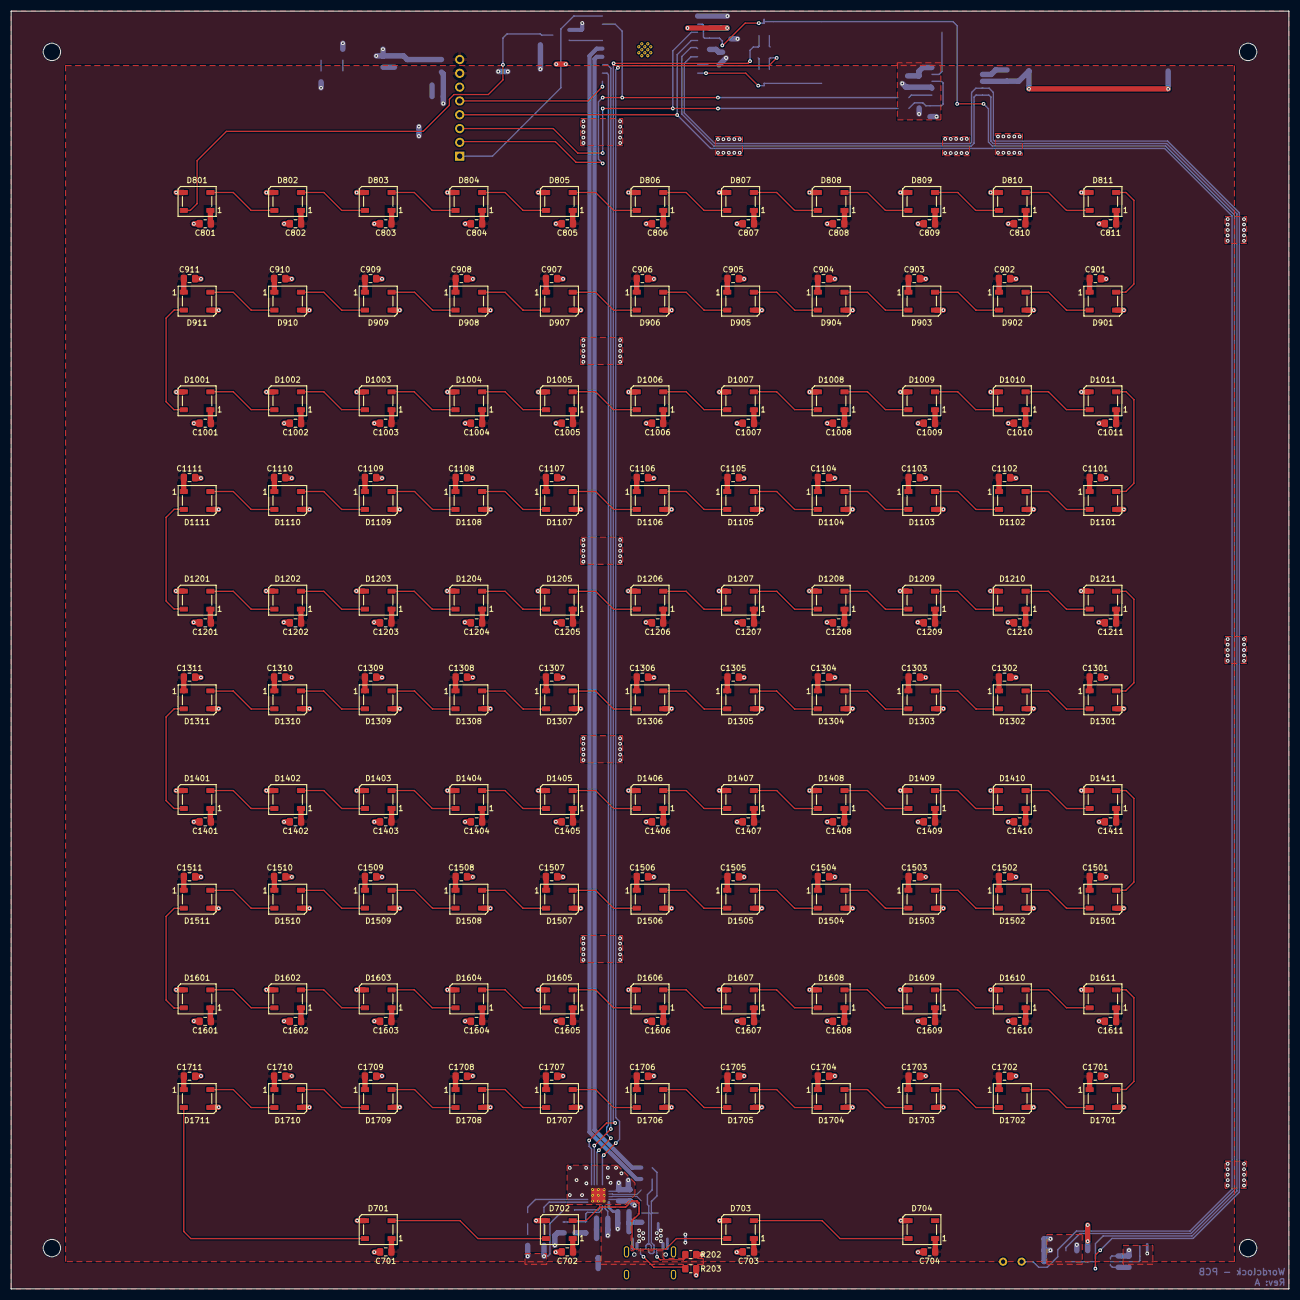
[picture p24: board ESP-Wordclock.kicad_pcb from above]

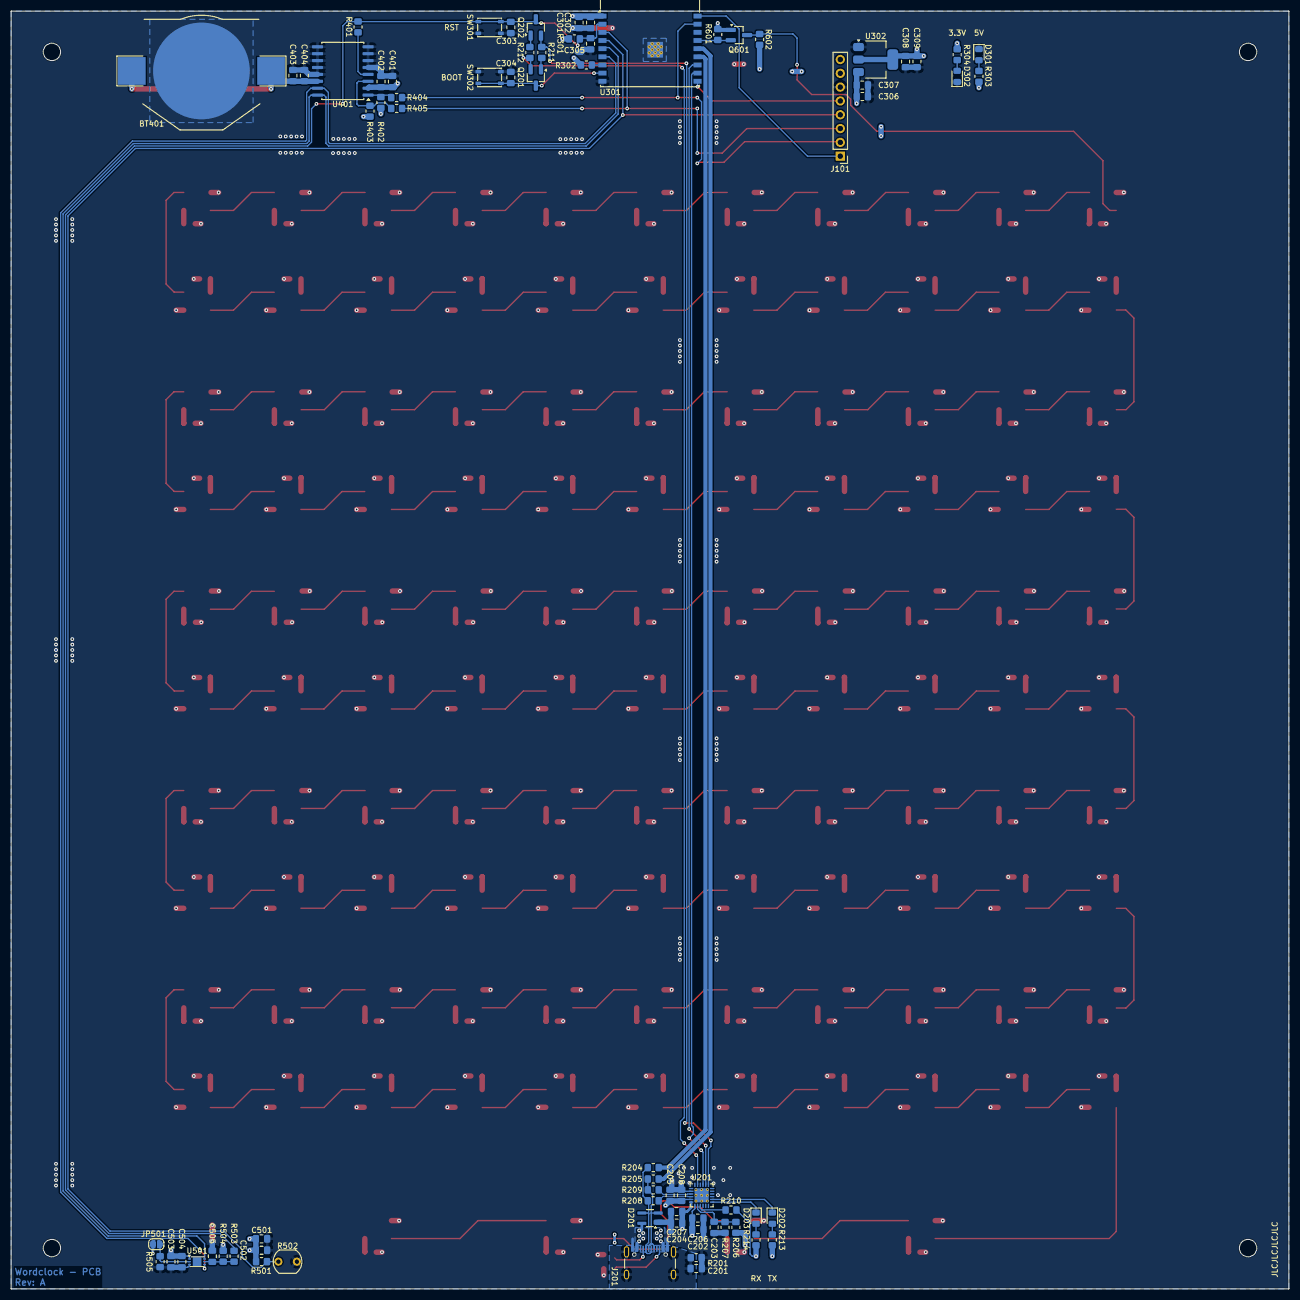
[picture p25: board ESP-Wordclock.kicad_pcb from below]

Board: 2 copper layers, 235.0 x 235.0 mm, 307 parts (73 on the bottom side), 157 nets.

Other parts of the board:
H1, H2, H3, H4: MountingHole_3.2mm_M3

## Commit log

2024-10-27 Add: Initial commit, changed the PCB to a submodule inside the official Multilayout-ESP-Wordclock
    [BrightnessSensor.kicad_sch, ESP-Wordclock.kicad_pcb, ESP-Wordclock.kicad_sch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]
2024-10-27 Mod: Checked a few things and added the power limitation text to the LEDs page
    [BrightnessSensor.kicad_sch, ESP-Wordclock.kicad_sch, LEDs.kicad_sch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]
2024-10-27 Mod: Changed the page number of the MCU and USB page
    [ESP-Wordclock.kicad_sch, MCU.kicad_sch, USB.kicad_sch]
2024-10-27 Fix: Some errors from the ERC
    [BrightnessSensor.kicad_sch, ESP-Wordclock.kicad_sch, LEDs.kicad_sch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]
2024-10-27 Add: Vendor no. and footprints
    [BrightnessSensor.kicad_sch, ESP-Wordclock.kicad_sch, LEDs.kicad_sch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]
2024-10-29 Mod: Changed parts to match with both vendors
    [BrightnessSensor.kicad_sch, ESP-Wordclock.kicad_sch, LEDs.kicad_sch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]
2024-10-29 Add: BOM_A.pdf exported BOM as .csv and generated a .pdf form the .csv
2024-11-01 Add: Header for empty pins of the ESP32 and added more 0R resistors to break up some connections
    [ESP-Wordclock.kicad_sch, RTC.kicad_sch]
2024-11-01 Fix: Name of the battery cell. Run ERC and created finished schematic, ready for the layout
    [ESP-Wordclock.kicad_sch, RTC.kicad_sch]
2024-11-01 Fix: Annotation of the LEDs
    [LEDx11.kicad_sch, LEDx4.kicad_sch]
2024-11-01 Add: BasePCB and added edge cut, holes, dimentions and LEDs with their caps
    [ESP-Wordclock.kicad_pcb]
2024-11-01 Fix: USB labels for differential pairs
    [USB.kicad_sch]
2024-11-01 Add: Componentes and created first routes
    [ESP-Wordclock.kicad_pcb]
2024-11-05 Mod: Almost finished layout for the USB-C
    [ESP-Wordclock.kicad_pcb]
2024-11-10 Mod: Layout, finished the layout. Changed the voltage pins of J101
    [ESP-Wordclock.kicad_pcb, ESP-Wordclock.kicad_sch]
2024-11-10 Add: ESP-Wordclock.step
    [ESP-Wordclock.step]
2024-11-10 Fix: ESP-Wordclock.kicad_pcb, run DRC and fixed errors
    [ESP-Wordclock.kicad_pcb]
2024-11-12 Mod: Moved LEDs for the minutes 3 mm down and reexported all relevant files agian
    [ESP-Wordclock.kicad_pcb, ESP-Wordclock_A.step]
2024-11-17 Add: JLCPCB Database and selected components for the assembly
    [BrightnessSensor.kicad_sch, ESP-Wordclock.kicad_pcb, ESP-Wordclock.kicad_sch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]
2024-11-17 Add: JLCPCB order number placeholder
    [ESP-Wordclock.kicad_pcb]
2024-11-17 Mod: Exported all files
    [ESP-Wordclock_A.step]
2024-11-17 Fix: JLCPCB production data to be correct for production
    [ESP-Wordclock.kicad_pcb, RTC.kicad_sch]
2024-11-25 Fix: Part no. of D201, because it was the wrong one
    [USB.kicad_sch]
2024-11-25 Mod: Updated date and fixed some typo
    [BrightnessSensor.kicad_sch, ESP-Wordclock.kicad_sch, LEDs.kicad_sch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]
2024-11-25 Mod: Updated the whole PCB, run DRC and re-exported all manufacturing files
    [ESP-Wordclock.kicad_pcb]
2024-11-25 Fix: Wrong LCSC part no. for U401
    [ESP-Wordclock.kicad_pcb]
2024-11-25 Mod: Re-exported all 3d files
    [ESP-Wordclock_A.step]

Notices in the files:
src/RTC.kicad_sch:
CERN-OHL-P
